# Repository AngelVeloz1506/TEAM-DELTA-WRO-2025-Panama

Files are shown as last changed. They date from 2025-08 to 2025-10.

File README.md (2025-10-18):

# TEAM DELTA — WRO 2025 (Future Engineers · Panama)

<p align="center" style="background-color:#1c1c1c; padding:20px; border-radius:12px;">
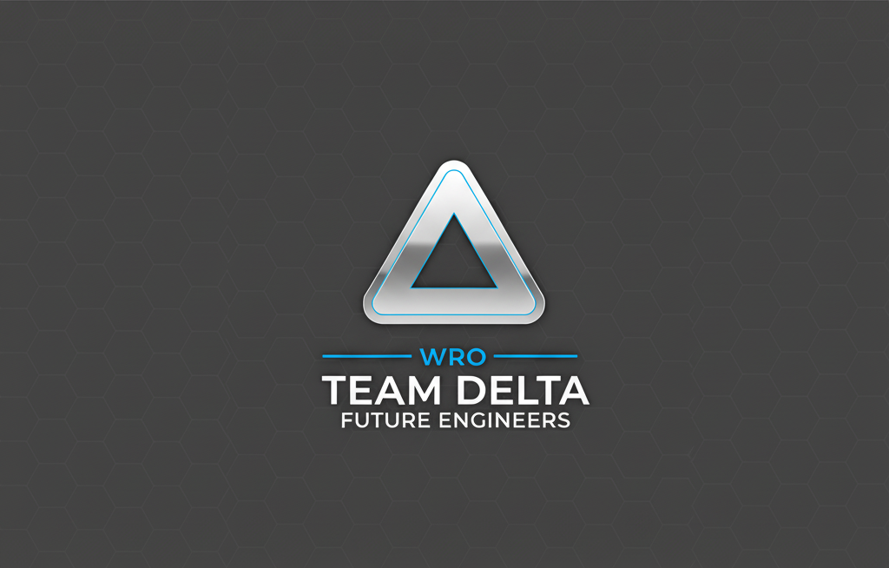
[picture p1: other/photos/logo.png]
Team Delta Logo
  
</p>

**Pontificia Universidad Católica Madre y Maestra (PUCMM) — Dominican Republic**  
Autonomous Vehicle Project for the **World Robot Olympiad 2025**, Future Engineers Category.

This repository documents the complete development of our robot — covering its **design, hardware, programming, and testing**.  



---

## Sections

<h2><a href="other/team/README.md">About Us</a></h2>

Team members, coach, and individual responsibilities.  
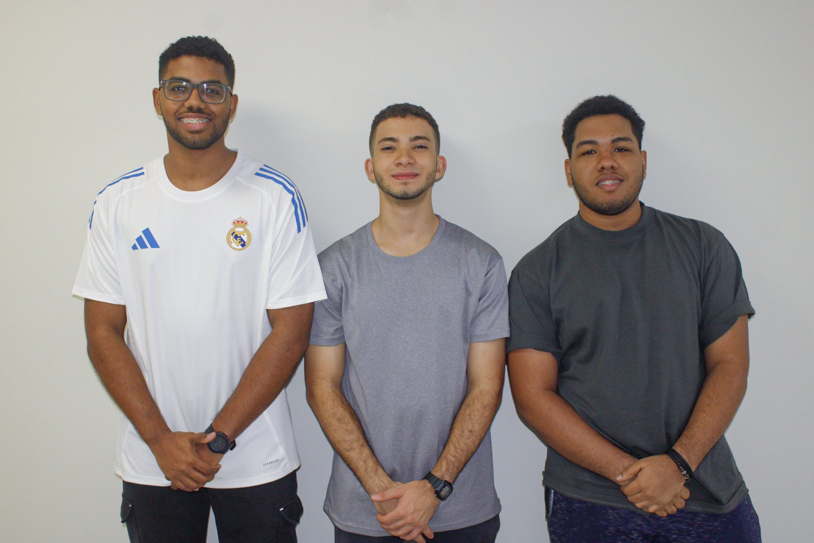
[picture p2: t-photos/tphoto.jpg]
About Us


<h2><a href="schemes/README.md">Hardware</a></h2>

Electronic components, wiring, power systems, and schematics.  
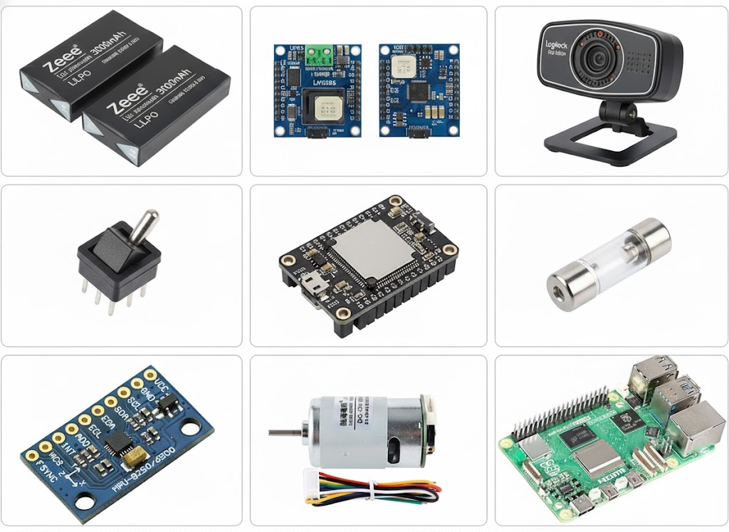
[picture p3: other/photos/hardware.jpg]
Hardware


<h2><a href="models/README.md">3D Design</a></h2>

Mechanical structure, chassis layout, and design evolution.  
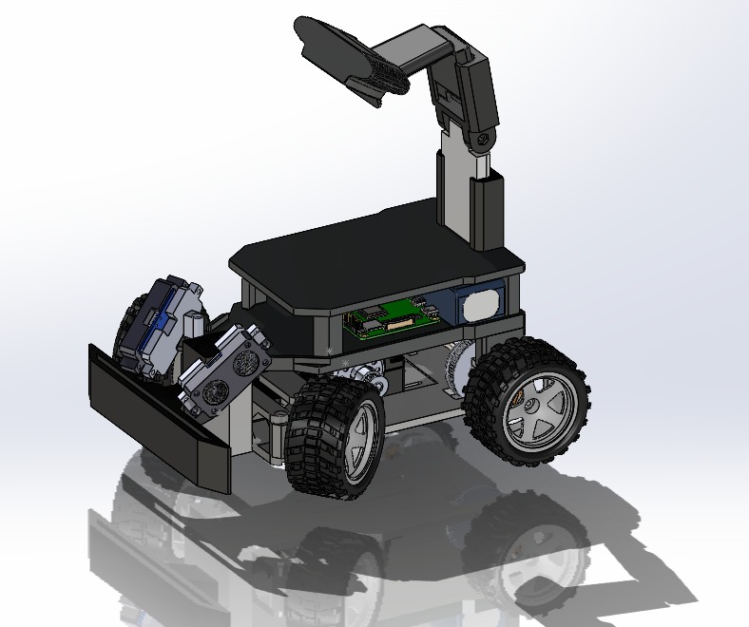
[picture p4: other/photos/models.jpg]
3D Design


<h2><a href="src/README.md">Software</a></h2>

Control logic, firmware explanation, and system architecture.  
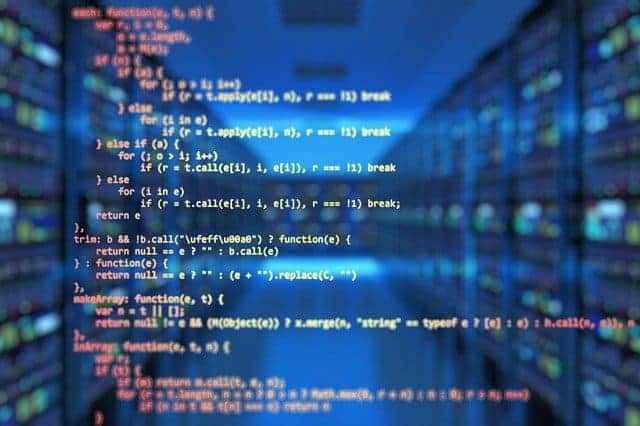
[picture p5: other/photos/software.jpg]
Software


<h2><a href="videos/README.md">Videos</a></h2>

Test runs, internal trials, and WRO challenges.  
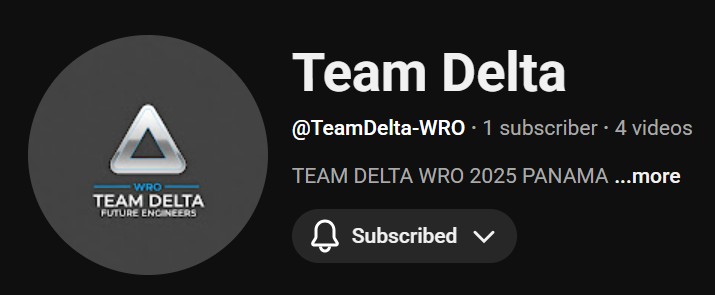
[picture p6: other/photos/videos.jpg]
Videos


<h2><a href="t-photos/README.md">Team Photos</a></h2>

Official and funny team pictures.  
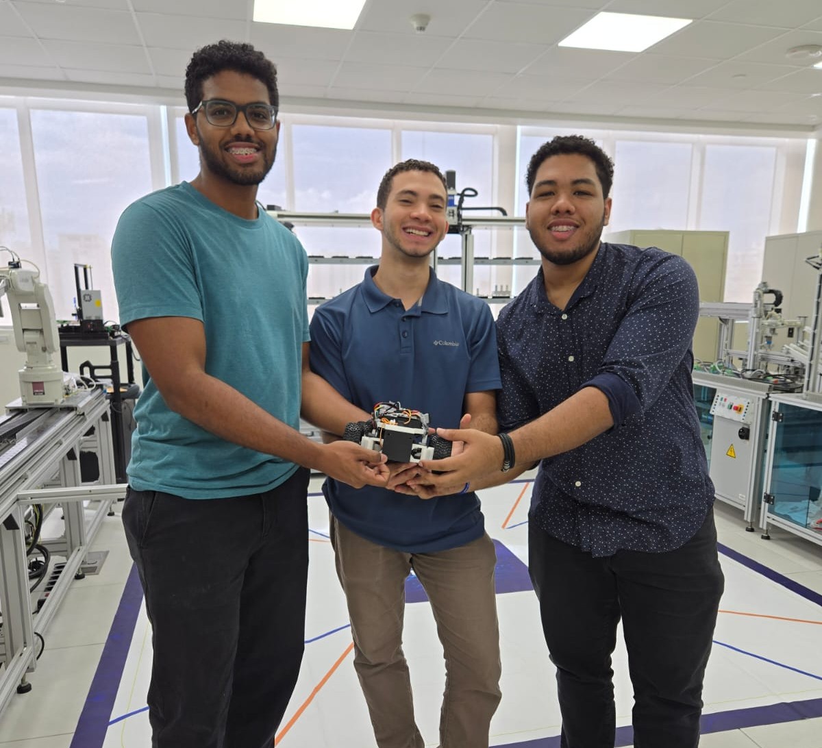
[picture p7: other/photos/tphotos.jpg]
Team Photos


<h2><a href="v-photos/README.md">Vehicle Photos</a></h2>

Design and evolution of the robot through different versions.  
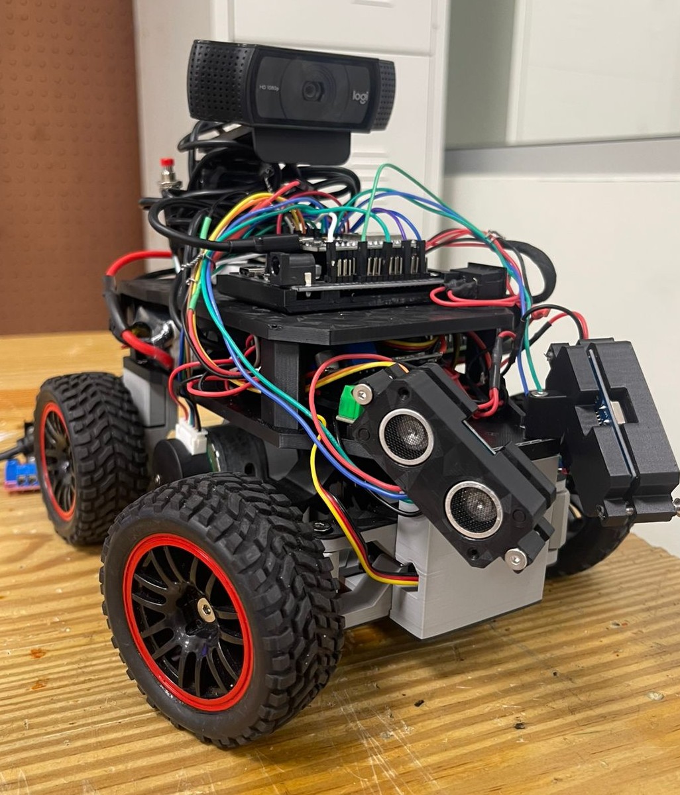
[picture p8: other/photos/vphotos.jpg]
Vehicle Photos


---

## Summary

**TEAM DELTA Δ** is committed to engineering excellence, innovation, and teamwork.  
This documentation serves as a transparent record of our journey to the **WRO 2025** stage,  
where mechanical design, electrical systems, and embedded control come together to build an autonomous vehicle capable of intelligent navigation.

---

*© 2025 TEAM DELTA – PUCMM · All rights reserved.*

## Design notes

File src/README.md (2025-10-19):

   This module implements the control logic for an autonomous robot car using:
   - **ESP32** as the main microcontroller  
   - **Servo motor** for Ackermann steering  
   - **1 DC motor** driven by a **DRV8871 H-Bridge** (PWM + brake)  
   - **2 ultrasonic sensors (HC-SR04)** for left/right distance measurement  
   - **MPU6050 IMU** for yaw estimation (gyro integration)  
   - **Incremental encoder** (channel A + channel B for direction)  
   - **Start button** with blocking logic at startup  

   ---

   ## System Overview

   1. **Sensing**
      - **Ultrasonics**: measure left/right distances with a **median of 3** for robustness.  
      - **IMU (MPU6050)**: reads raw accelerometer/gyroscope and integrates **gz** to estimate **yaw angle** in degrees.  
      - **Encoder**: ISR on channel A, with channel B defining the rotation direction. Used to calculate **position pulses** and **RPM** every 300 ms.

   2. **Control Strategy**
      - **Steering**: computed from the **difference** between left/right distances (`diff = d1 - d2`) mapped to servo angles.  
      - **Speed**: mapped from **accelerometer X-axis** (accelX in m/s²) to PWM duty cycle (115–255).  

   3. **Actuation**
      - **Servo**: controlled with `Servo.write(angle)`.  
      - **Motor**: controlled via `ledcWrite(motorPin, duty)` at **10 kHz**; `otherPin` is used for active brake.  

   4. **State Management**
      - **Startup lock**: waits for button press before motor activation.  
      - **Stop condition**: if `pos >= 3200` pulses, motor stops permanently.  

   ---

   ## Hardware and Pin Mapping

   ### Encoder
   - `SA = 27` → Channel A (interrupt, RISING)  
   - `SB = 14` → Channel B (direction sense)  

   ### Start Button
   - `BUTTON_PIN = 23` (INPUT_PULLUP; pressed = LOW)  

   ### Ultrasonics
   - Right sensor → `trigPin1 = 25`, `echoPin1 = 26`  
   - Left sensor → `trigPin2 = 32`, `echoPin2 = 33`  
   > **Note:** readings use **median of 3** with timeout handling.  

   ### Servo
   - `servoPin = 15`  
   - Default center (to be calibrated): `SERVO_CENTER = 87`  

   ### Motor + DRV8871
   - **PWM (speed)**: `motorPin = 12` (LEDC @ 10 kHz, 8-bit)  
   - **Direction/Brake**: `otherPin = 13`  

   ### IMU (MPU6050, I2C)
   - Connected via ESP32 default SDA/SCL  
   - Initialized with `mpu.initialize();`  

   ---

   ## Key Variables and Constants

   - `PULSOS_POR_REV = 12` → pulses per revolution of encoder  
   - `ENCODER_INTERVAL = 300 ms` → window for RPM calculation  
   - `PRINT_INTERVAL = 200 ms` → interval for logging yaw (currently commented)  
   - `yaw` → integrated heading in degrees  
   - `pos` → encoder pulses (signed)  
   - `rpm` → calculated every 300 ms  
   - `YAW_THRESHOLD = 5°`, `DIST_TRIGGER = 100 cm` (declared, not used yet)  

   ---

   ## IMU (Yaw Calculation)

   1. Read raw values:  
      ```cpp
      mpu.getMotion6(&ax, &ay, &az, &gx, &gy, &gz);
      ```
   2. Convert `gz` to deg/s:  
      ```cpp
      yaw_rate = gz / 131.0;
      ```
   3. Integrate:  
      ```cpp
      yaw += yaw_rate * dt;  // dt in seconds
      ```
   > No drift correction (no complementary or Kalman filter). Long runs will accumulate error.  

   ---

   ## Encoder: Position and RPM

   - **ISR** (`readEncoder`) increments or decrements `pos` depending on channel B.  
   - RPM calculation every 300 ms:  
   ```cpp
   delta = pos - lastPos;
   rpm = (delta / PULSOS_POR_REV) * (60000.0 / ENCODER_INTERVAL);
   ```  

   ---

   ## Ultrasonic Readings

   - `medirUna(trig, echo)`:  
   - Sends 10 µs trigger pulse  
   - Reads echo with timeout (25 ms max)  
   - Converts duration to cm  
   - Returns 400 if invalid (timeout or <3 cm)  

   - `medirDistancia(trig, echo)`:  
   - Takes **3 readings** with delays  
   - Returns the **median value**  

   ---

   ## Steering Logic

   - Computes difference: `diff = d1 - d2`  
   - Maps difference to servo angle:  
   ```cpp
   servoAngle = map(diff, -10, 10, 70, 110);
   servoAngle = constrain(servoAngle, 50, 120);
   serv.write(servoAngle);
   ```

   ---

   ## Motor Control (DRV8871)

   - Configured at **10 kHz, 8-bit resolution**  
   - Speed control via:  
   ```cpp
   ledcWrite(motorPin, duty);
   digitalWrite(otherPin, LOW);
   ```
   - Brake:  
   ```cpp
   digitalWrite(otherPin, HIGH);
   ledcWrite(motorPin, 255);
   delay(100);
   ledcWrite(motorPin, 0);
   ```

   ---

   ## Program Lifecycle

   ### `setup()`
   1. Initialize Serial, encoder pins, attach ISR  
   2. Start I2C and IMU  
   3. Configure ultrasonic pins  
   4. Configure start button (INPUT_PULLUP)  
   5. Attach servo, move to neutral  
   6. Setup motor PWM (LEDC)  
   7. **Wait loop**: blocks until button pressed for 2 s  

   ### `loop()`
   1. Measure distances (left/right ultrasonic)  
   2. Update yaw from IMU integration  
   3. Update RPM from encoder (every 300 ms)  
   4. Update steering angle (from ultrasonic diff)  
   5. Compute motor velocity (from accelX) and apply PWM  
   6. Stop permanently if encoder pulses exceed 3200  

   ---

   ## Calibration

   - **Servo center**: adjust `SERVO_CENTER` or apply offset until robot drives straight.  
   - **Ultrasonic mapping**: adjust `map(diff, -10..10)` to match your robot’s scale.  
   - **Motor scaling**: ensure accel axis matches forward movement; rescale if needed.  
   - **Encoder PULSOS_POR_REV**: must match your encoder hardware.  

   ---

   ## Safety Notes

   - Startup is blocked until button press (prevents accidental motion).  
   - Servo is constrained to 50–120° to avoid hardware damage.  
   - Motor brake is available but not actively used in main loop.  
   - Ultrasonics use timeout + median filtering to reduce noise.  
   - IMU yaw has drift; not suitable for long-term navigation without fusion.  

   ---

   ## Function Reference

   - `medirUna(trig, echo)` → single ultrasonic read  
   - `medirDistancia(trig, echo)` → median of 3 ultrasonic reads  
   - `readEncoder()` → ISR to update encoder pulses  
   - `setMotorSpeed(speed)` → set motor duty cycle (basic)  
   - `brakeMotor()` → apply active brake  

---

   ## Suggested Improvements

   - Add **PID speed control** using encoder feedback  
   - Use **complementary filter** for yaw correction  
   - Implement **fail-safe stop** when ultrasonic < threshold  
   - Expand to **bi-directional motor control** (two PWM inputs)  
   - Add **LED or buzzer** for startup/stop feedback  

---

## Previous Versions

For earlier iterations of the robot’s control system — including motion-only logic, PID stabilization, Pixy2 vision integration, and IMU-based yaw reset — see the  
**[Releases documentation](Releases/README.md)** located in the `src/Releases` directory.

This section details the evolution of the system through multiple code versions (`open-v1.ino` to `open-v4.ino`), showing how control strategies and sensor integration improved toward the final design.

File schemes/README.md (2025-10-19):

# Hardware

This section covers the **electronics, components (BOM), power**, and **schematics**.

---

## Bill of Materials (BOM)

| **Component** | **Qty** | **Notes** |
|---|---|---|
| [Raspberry Pi 5 (16 GB)](https://www.amazon.com/-/es/SC1113-Raspberry-Pi-5-16GB/dp/B0DSPYPKRG/ref=sr_1_1?sr=8-1) | 1 | Companion computer for vision & AI tasks |
| [ESP32](https://www.amazon.com/-/es/ESP-WROOM-32-Desarrollo-Microcontrolador-Procesador-Compatible/dp/B08D5ZD528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) | 1 | Main MCU, 3.3 V logic |
| [Logitech C920 Webcam](https://www.amazon.com/-/es/Logitech-correcci%C3%B3n-funciona-Facetime-port%C3%A1til/dp/B085TFF7M1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) | 1 | 1080p video input for vision processing |
| [HC-SR04 Ultrasonic Sensor](https://www.amazon.com/-/es/ultras%C3%B3nico-HC-SR04-distancia-Mega2560-Conjunto/dp/B01COSN7O6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) | 3 | Front, Left, Right (Echo shifted to 3.3 V) |
| [DRV8871 H-Bridge driver](https://www.amazon.com/-/es/Teyleten-DRV8871-controlador-H-puente-m%C3%B3dulo/dp/B0DN66P9XW/ref=sr_1_3?sr=8-3) | 2 | One per DC motor |
| [HS-485HB Servo (steering)](https://www.amazon.com/-/es/HS-485HB-Est%C3%A1ndar-Anal%C3%B3gico-Karbonite-Aircraft/dp/B0F9YB8P4B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) | 1 | 5–6 V supply, high torque |
| [DC Motor 12 V (RS555 model)](https://www.ebay.com/itm/155702183252?_skw=motor+encoder+r555+12v) | 2 | RS555 brushed motor |
| [MPU6050 (I2C)](https://www.amazon.com/giroscopio-magn%C3%A9tico-aceleraci%C3%B3n-acelerador-magnet%C3%B3metro/dp/B01I1J0Z7Y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) | 1 | IMU (gyro + accel) |
| [LiPo Battery 11.4 V 3000 mAh](https://www.ebay.com/itm/395464923168?_skw=zeee+11.4v+lipo+3s+3000mah) | 1 | XT60 recommended |
| [LM2596 / HW-083 step-down regulator](https://www.amazon.com/convertidor-reguladores-ajustables-recomendado-alimentaci%C3%B3n/dp/B0FDB25T5L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) | 2+ | 12→6 V (servo) and 12→5/3.3 V (logic) |
| [Main switch](https://www.amazon.com/interruptor-basculante-encendido-precableado-autom%C3%B3vil/dp/B07S2QJKTX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)|

> **Tip:** Always maintain a **common GND** across battery, drivers, sensors, and MCU.

---

## Key Modules

### Raspberry Pi 5 (16 GB)

<p align="center">
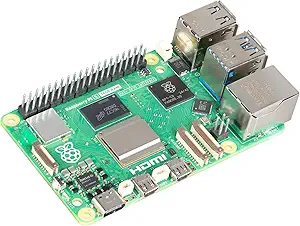
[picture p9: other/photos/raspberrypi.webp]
  <br>
  <em>The Raspberry Pi 5 serves as the companion computer for AI and computer vision tasks.<br>
  It communicates with the ESP32 via UART, I2C, or Ethernet for real-time data exchange.<br>
  Capable of running OpenCV, TensorFlow, and SLAM algorithms for perception and control.</em>
</p>

---

### ESP32 Controller

<p align="center">
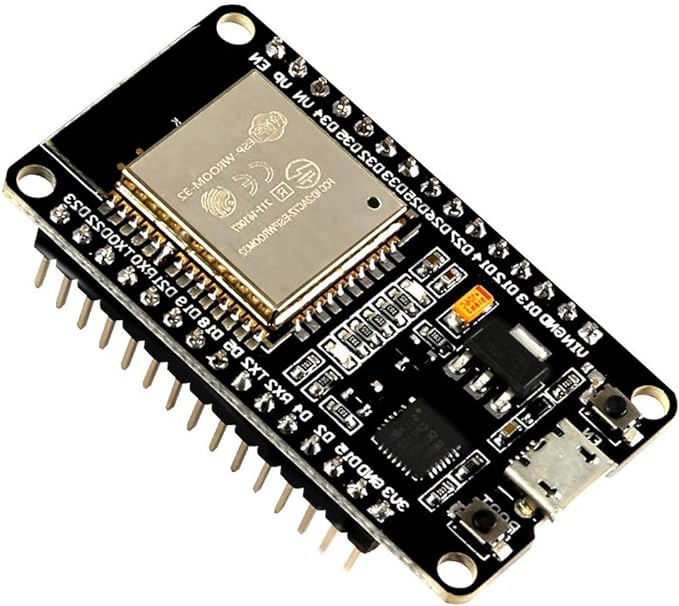
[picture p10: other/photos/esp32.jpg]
  <br>
  <em>The ESP32 functions as the main MCU, managing motor control, sensors, and communications.<br>
  Its dual-core architecture enables reliable real-time performance and parallel task execution.</em>

| Feature | Value |
|--|--|
| Cores | Xtensa LX6 dual-core |
| Voltage | 3.3 V |
| I/O Pins | 30+ |
| PWM (LEDC) | Yes |
| Flash | 4 MB |

</p>
---

### Camera (Logitech C920)

<p align="center">
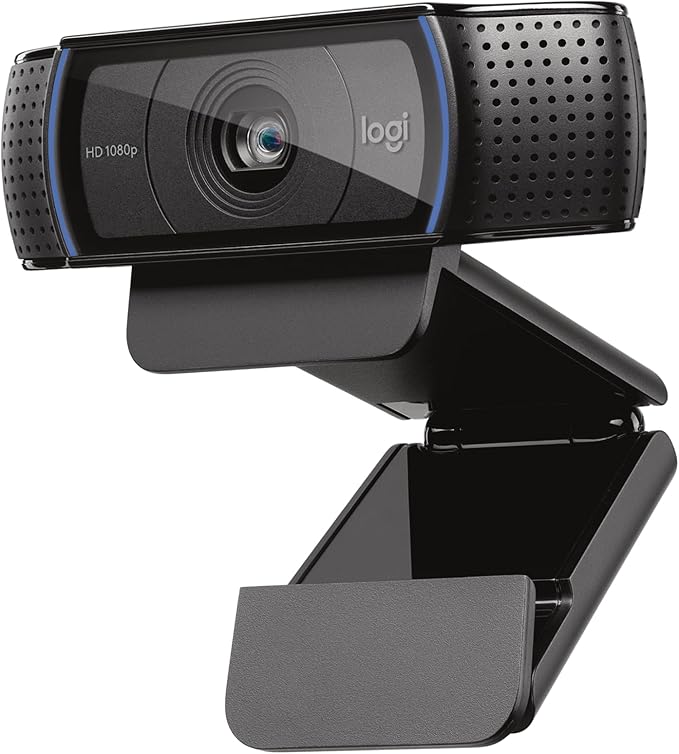
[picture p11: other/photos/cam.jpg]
  <br>
  <em>A 1080p USB camera used by the Raspberry Pi for lane and object detection.<br>
  Provides clear video input under different lighting conditions for AI vision processing.</em>
</p>

---

### Ultrasonic Sensor (HC-SR04)

<p align="center">
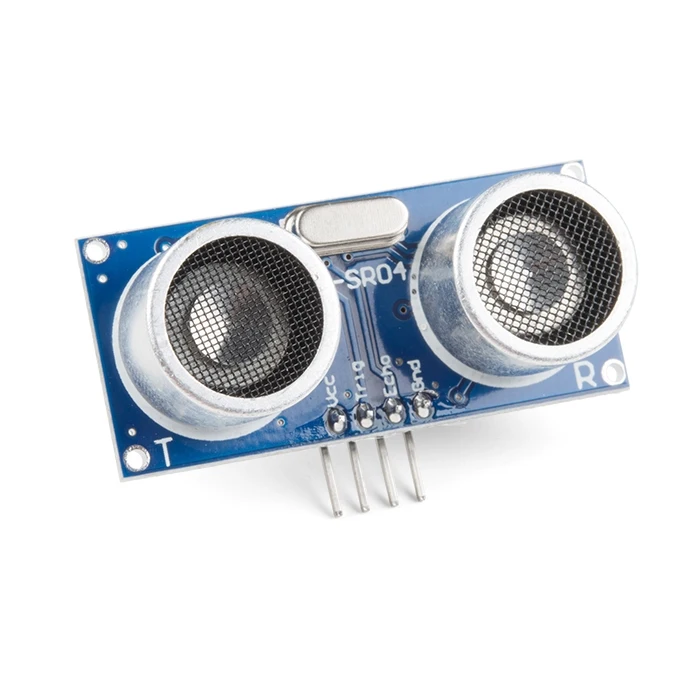
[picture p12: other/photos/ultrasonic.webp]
  <br>
  <em>Two ultrasonic modules are mounted front, left, and right to measure obstacle distance.<br>
  Each runs at 5 V (with 3.3 V logic shift) and 30 ms timeout for safe navigation.</em>
</p>

---

### H-Bridge (DRV8871)

<p align="center">
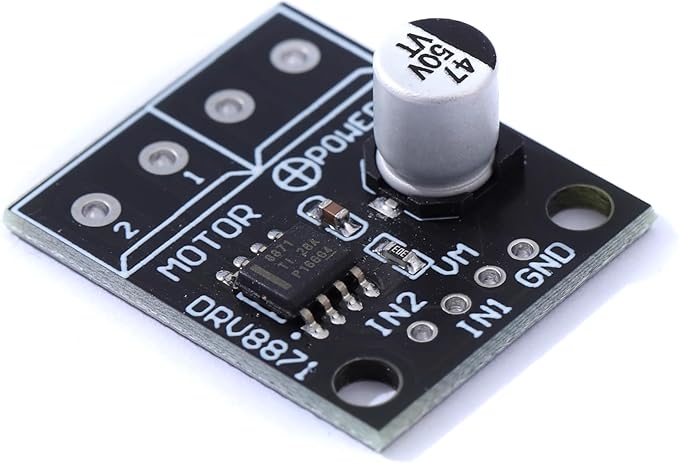
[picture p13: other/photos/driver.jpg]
  <br>
  <em>The DRV8871 controls each 12 V DC motor via PWM signals, allowing bidirectional rotation.<br>
  Supports current limiting and thermal protection for safe operation.</em>
</p>

---

### Servo (HS-485HB)

<p align="center">
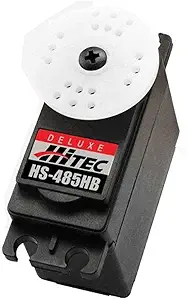
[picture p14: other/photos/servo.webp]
  <br>
  <em>The HS-485HB servo controls Ackermann steering using a dedicated 5–6 V supply (≥ 2 A).<br>
  Durable Karbonite gears ensure smooth and responsive direction control.</em>
</p>

---

### DC Motor (RS555 Model)

<p align="center">
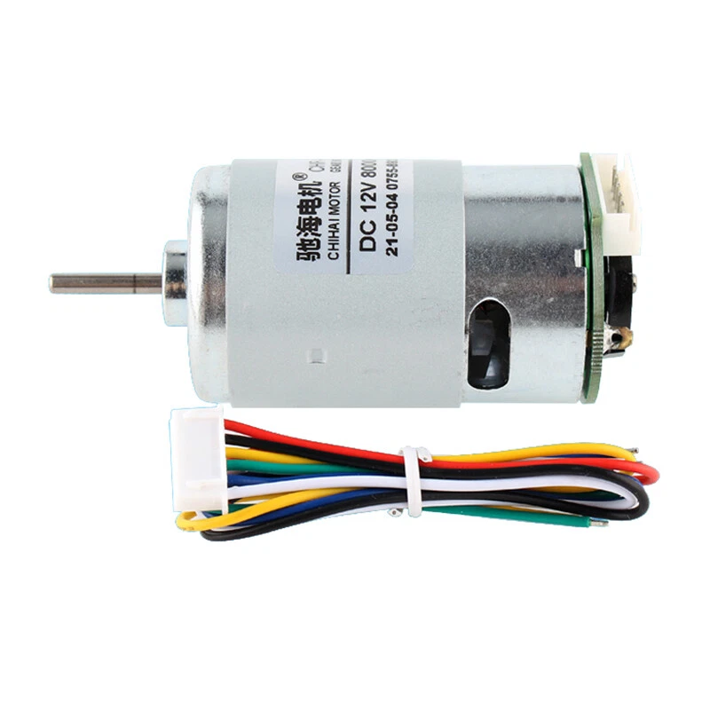
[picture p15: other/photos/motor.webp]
  <br>
  <em>A RS555 12 V brushed DC motor drive the rear wheels through an H-Bridges.<br>
  Provide high torque and stable speed under load conditions.</em>
</p>

---

### IMU (MPU6050)

<p align="center">
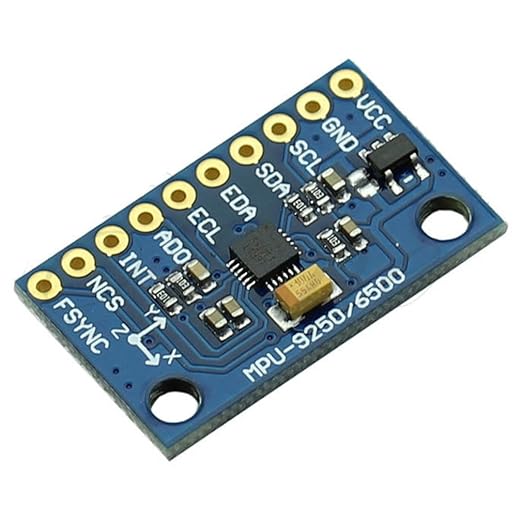
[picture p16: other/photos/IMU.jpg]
  <br>
  <em>The MPU6050 combines a 3-axis accelerometer and gyroscope to detect orientation and motion.<br>
  Sends I2C data to the ESP32 for stability and trajectory correction.</em>
</p>

---

### Battery (LiPo 11.4 V 3000 mAh)

<p align="center">
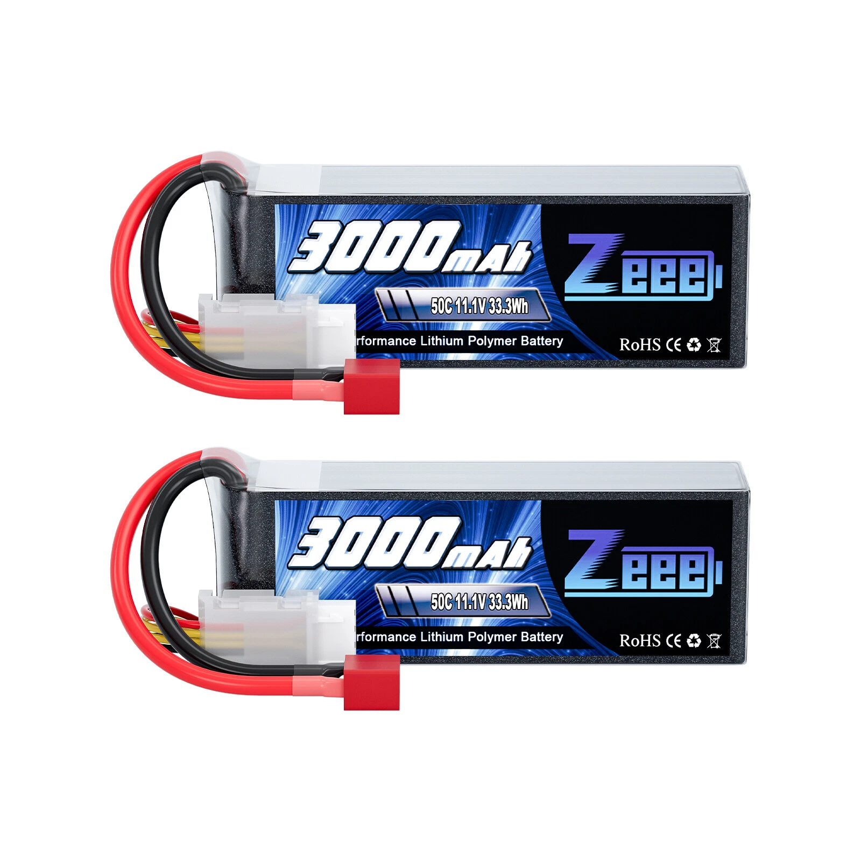
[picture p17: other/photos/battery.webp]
  <br>
  <em>A 3-cell LiPo battery powers all components with 11.4 V nominal voltage and XT60 connector.<br>
  Protected by inline fuses for safety and stable current delivery.</em>
</p>

---

### Step-Down Regulator (LM2596)

<p align="center">
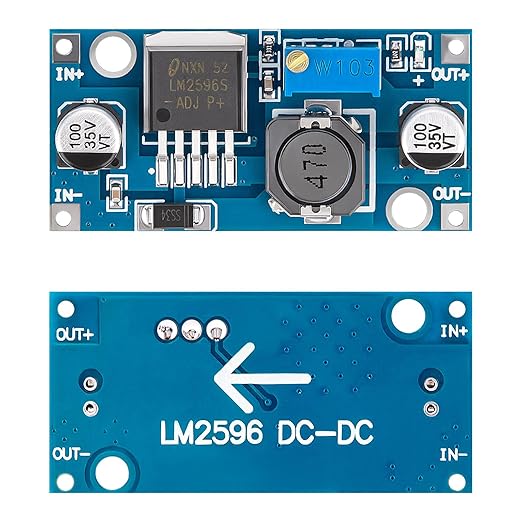
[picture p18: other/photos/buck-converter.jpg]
  <br>
  <em>LM2596 buck converters step 12 V down to 6 V (for servo) and 5/3.3 V (for logic).<br>
  Include adjustable outputs and thermal protection for reliable voltage regulation.</em>
</p>

---

### Main Switch

<p align="center">
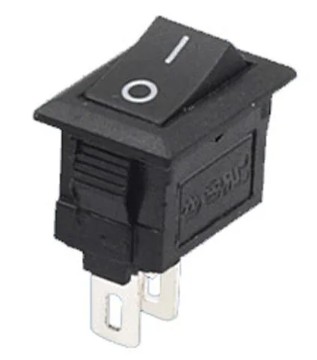
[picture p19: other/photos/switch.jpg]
  <br>
  <em>Main power switch ensures safe system startup.<br>
  Provides fast disconnect during maintenance or emergency shutdown.</em>
</p>

---

## Schematics

- [Delta Schematic Design (PDF)](../schemes/Delta%20schematic%20design.pdf)

**Preview**

<p align="center">
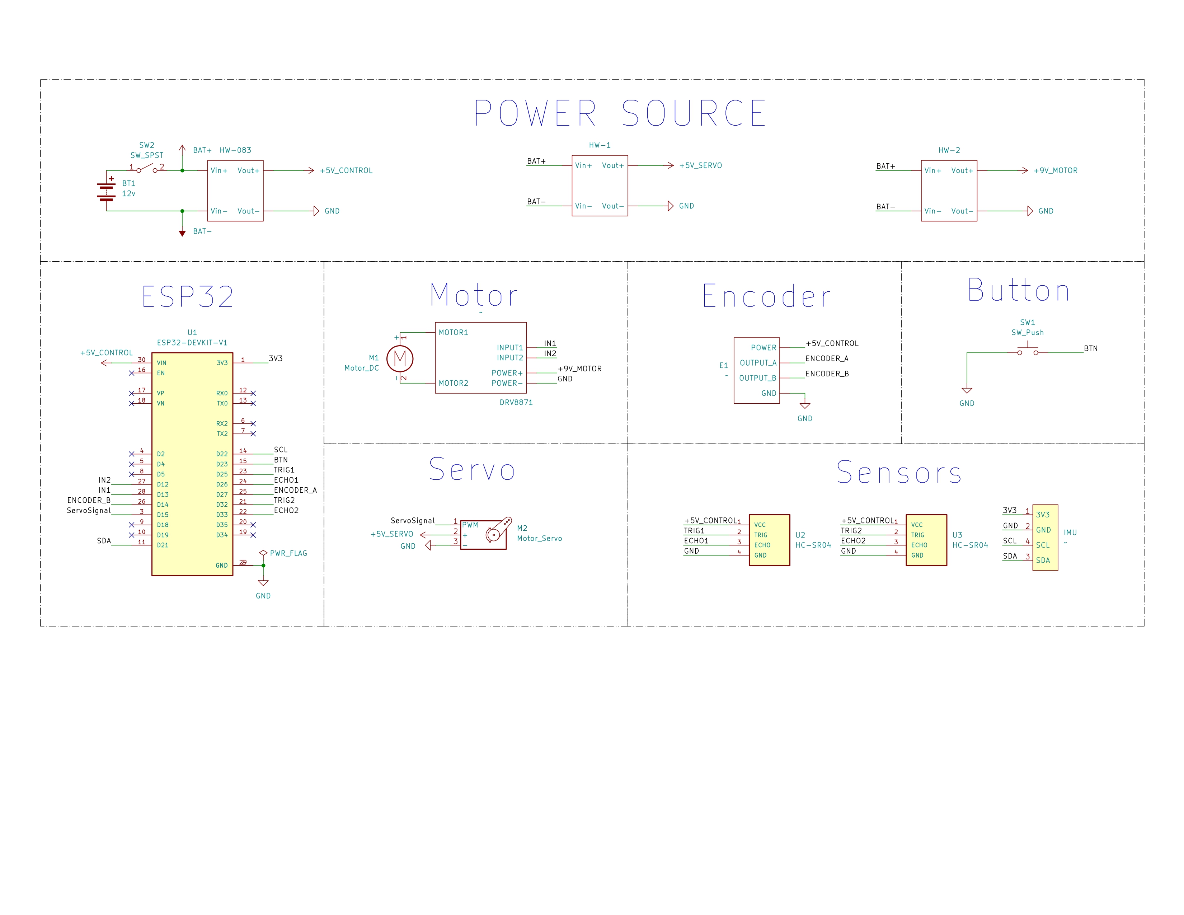
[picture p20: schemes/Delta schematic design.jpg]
  <br>
  <em>This diagram shows the ESP32, DRV8871 drivers, sensors, servo, regulators, and power distribution.</em>
</p>

---

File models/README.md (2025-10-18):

## Robot Design Evolution

This section showcases the **evolution of TEAM DELTA’s robot design**, from the very first mechanical prototype to the latest integrated version prepared for autonomous testing.  
Each stage demonstrates improvements in structure, balance, electronics integration, and overall system efficiency — reflecting the team’s continuous optimization process.

---

## Version 1 (V1)

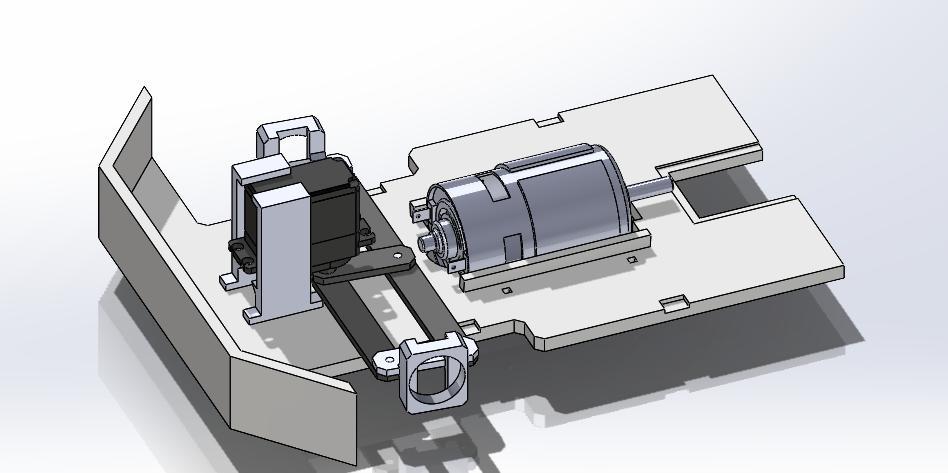
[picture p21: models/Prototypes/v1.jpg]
Version V1


The **first prototype** focused primarily on the **mechanical foundation and traction system** of the vehicle.  
At this stage, the design included a **simple frame** with a single DC motor mounted on a **metal support**, used to validate the basic drivetrain configuration.  
The purpose of V1 was to verify **axle alignment, transmission efficiency**, and **structural rigidity** under initial motion tests.  

No electronic modules or sensors were included yet — this prototype served as the **core mechanical proof of concept**.  
It helped the team understand torque distribution, friction losses, and the required power to achieve stable straight-line motion before integrating more advanced components.

---

## Version 2 (V4)

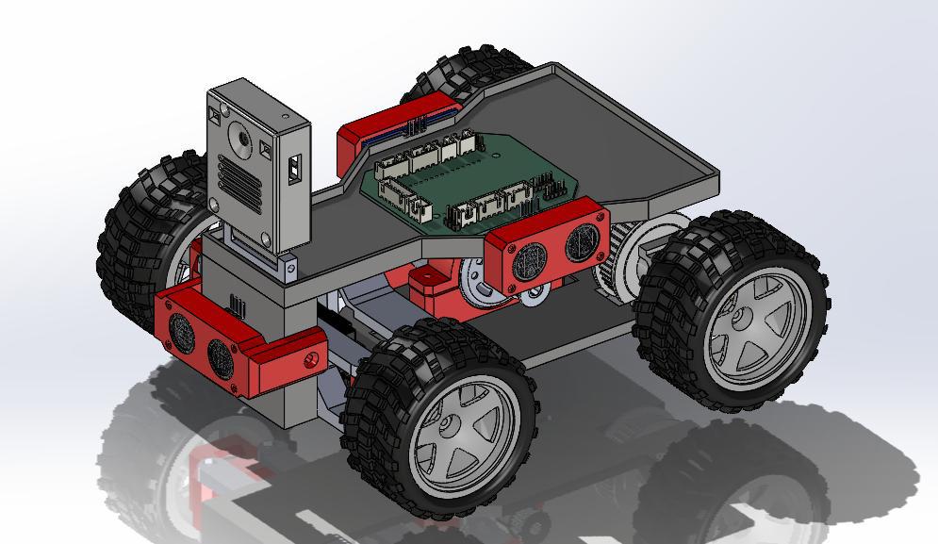
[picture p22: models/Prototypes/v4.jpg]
Version V4


The **second major iteration (V4)** introduced significant mechanical refinements and structural improvements.  
This version incorporated **four fully functional wheels**, connected through an upgraded **axle and gear system**, designed for improved torque balance and smoother motion.  

A **modular frame** was implemented, allowing rapid adjustments of the **motor position**, **axle supports**, and **servo linkages**.  
Weight distribution and the **center of gravity** were carefully optimized to enhance **stability**, particularly during turning and acceleration.  

The improved structural symmetry and reinforced chassis reduced vibrations and lateral drift, making V4 a **milestone version** in achieving consistent mechanical performance.

---

## Version 3 (V6.5)

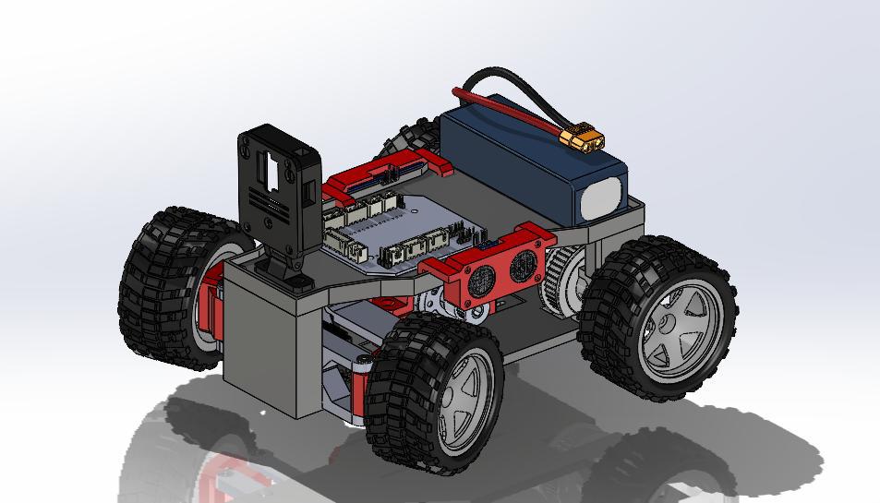
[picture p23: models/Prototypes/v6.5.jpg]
Version V6.5


The **third and most advanced version (V6.5)** represents the transition to a **fully integrated mechatronic platform**.  
This iteration introduced a dedicated **electronics control board**, organized **cable routing**, and **sensor mounts** for the front modules.  

The chassis was redesigned to be **more compact and layered**, providing specific areas for the **battery**, **controller**, and **camera or distance sensors**.  
This version combines mechanical robustness with clean electronic integration, marking the first time the system was ready for **autonomy, telemetry, and algorithm testing**.  

With improved accessibility, modular spacing, and a clear layout for expansion, V6.5 stands as the foundation for the team’s final **competition-ready design** — compact, efficient, and easy to maintain.

---

## Version 4 (V7)

Version V7

The **final version (V7)** showcases the **complete integration** of mechanical, electrical, and software subsystems, making it the team’s **competition-ready robot**.  
This design focuses on **system reliability**, **cable management**, and **sensor calibration** for autonomous operation under WRO conditions.  

The chassis now includes a **better mount for the camera** with a better and wider view of the field, beter **component positioning**, and **adjustable mounts** for ultrasonic units.  

Additionally, this version introduced **fans** to optimize cooling a new  power switch just for the Raspberry Pi so we can control both power sources independently.

V7 stands as the **culmination of iterative testing, engineering precision, and team collaboration**, ready to represent Team Delta at the **WRO 2025 Future Engineers** competition in Panama.

---

Each iteration — from V1 to V7 — represents a clear evolution in **engineering maturity**, moving from mechanical experimentation to an integrated, intelligent robotic system.  
The process highlights the importance of **incremental design, testing, and optimization** in achieving a stable and reliable autonomous platform.

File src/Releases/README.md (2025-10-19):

# Open Challenge — Code Evolution

This folder documents the **progressive versions** of Team Delta’s control code for the  
**WRO 2025 Future Engineers — Open Challenge**.  

Each version builds upon the previous one, introducing new sensors, control strategies, and optimizations for autonomous driving stability, accuracy, and response.

---

## **Version 1 — Basic Motion Control (Reverse-Kick and Power Boost)**

**File:** `open-v1.ino`  
**Main Components:** ESP32 + Servo (steering) + DRV8871 motor driver  

This first version establishes the **fundamental movement routine** for the robot — combining PWM motor control and steering using a servo.

### **Core Features**
- Modular helper functions for acceleration, braking, and turning.  
- Implements **reverse-kick braking** in every turn (short reverse pulses).  
- Adds a **power boost** after each braking event for smooth reacceleration.  
- Performs **three sequential right turns**, with duty cycle increase after the first turn.  
- On the **final turn**, the robot performs a full stop sequence:  
  - Reverse + brake + coast sequence for a complete halt.  

### **Code Breakdown**
- **Pin and PWM setup:**  
  Defines two motor pins (`IN_PWM`, `IN_OTHER`) controlling the DRV8871 H-bridge.  
  The PWM signal on `IN_PWM` drives forward speed, while `IN_OTHER` can toggle direction.  
  PWM is configured with `ledcAttach(channel, freq, res)` and commanded with `ledcWrite(channel, duty)`.
- **Motor control helpers:**  
  - `setForwardDuty(duty)` sets normal forward torque.  
  - `reverseKick(duty, ms)` momentarily switches PWM to the opposite pin to create a **short reverse pulse**, effectively braking the motor.  
  - `brakeHard()` energizes both inputs for strong electrical braking.  
  - `coast()` releases both pins for a free-spin stop.
- **Servo motion:**  
  The servo turns fully right for a corner (`turnRightMaxPower()`) and returns to center (`returnCenterMaxPower()`), both under controlled PWM drive.  
- **Duty logic:**  
  After the first turn, the work duty increases (`+30`) to compensate for frictional slowdown.  
- **Final Stop:**  
  The final loop executes `finalBrakeStop()` — a hard brake, reverse pulse, and final coast to stop completely.

---

## **Version 2 — MPU6050 Integration + PID Pitch Stabilization**

**File:** `open-v2.ino`  
**Main Components:** ESP32 + **MPU6050** Accelerometer + Servo + DRV8871  

This iteration introduced the **first sensor-based feedback control system** to measure inclination and stabilize the platform in real time.

### **Key Additions**
- **PID controller** (`PID_v1`) for pitch stabilization.  
- **Moving average filtering** to smooth sensor readings.  
- **Manual reset button** to re-zero sensor offsets.  
- **Boost phase** at startup for initial acceleration, then regulated power.  

### **Code Breakdown**
- **Sensor initialization & readout (I²C):**  
  Initializes the IMU over I²C, then reads raw acceleration on X/Y/Z every loop.  
  Data is converted to g’s and fed into a **moving-average filter** (ring buffer) for noise reduction.
- **Pitch calculation:**  
  Uses trigonometry to compute tilt:  
  `pitch = atan2(x, sqrt(y² + z²)) * 180/π` (degrees).  
  The filtered **pitch** becomes the **PID Input**.
- **PID control → steering:**  
  `Setpoint = 0` (level). `myPID.Compute()` calculates a correction sent to the servo with a safe clamp (e.g., 50–130°).  
  Proper tuning of **Kp/Ki/Kd** balances reaction speed and overshoot.
- **Motor drive policy:**  
  The motor runs at a defined **work duty** while the servo continuously adjusts heading based on the PID output to maintain stability.

---

## **Version 3 — Pixy2 Vision Integration**

**File:** `open-v3.ino`  
**Main Components:** ESP32 + Pixy2 Camera + Servo + DRV8871  

This version added **computer vision** capabilities for **color-based object detection** using the Pixy2 sensor.

### **Main Functionalities**
- Detects color blocks (signatures 1–2) via SPI communication.  
- Implements a **search behavior** through short forward pulses.  
- When a target is detected, performs a **turn and boost** maneuver.  
- Keeps the servo centered when idle.

### **Code Breakdown**
- **Camera initialization & reading:**  
  `pixy.init()` followed by `pixy.ccc.getBlocks()` each cycle reads detected objects.  
  Iterates `pixy.ccc.blocks[]` and checks `m_signature` for target classes (1 or 2).
- **Search gait (pulse & read):**  
  The robot advances in **short PWM bursts** (e.g., 20 ms on / 30 ms off) to reduce motion blur and give the camera stable frames.
- **Target reaction:**  
  On detection: pause → steer to a fixed angle → **boost** for `BOOST_TIME` → settle to a cruise duty.  
  This produces a decisive “detect → orient → accelerate” behavior.
- **Idle posture:**  
  With no detections, the servo **re-centers** (e.g., 90°) to maintain a straight scan line.

---

## **Version 4 — MPU6050 Gyro Integration + Yaw Reset Logic**

**File:** `open-v4.ino`  
**Main Components:** ESP32 + MPU6050 IMU + Servo + DRV8871  

This iteration integrates a **6-axis IMU (MPU6050)** combining gyroscope and accelerometer data to manage **orientation and heading** in real time.

### **Major Features**
- Real-time **yaw integration** from gyroscope data (`gz`).  
- Automatic **yaw reset** every ~1.5 s to mitigate drift.  
- **Autonomous stop** after six resets (lap completion logic).  
- **Active braking** with a brief **reverse** before final halt.  
- **Dynamic speed mapping** from longitudinal acceleration.

### **Code Breakdown**
- **IMU reading & integration:**  
  Reads `ax, ay, az, gx, gy, gz`.  
  Computes loop `dt` and integrates yaw: `yaw += (gz/131.0) * dt`.
- **Control mapping:**  
  - **Steering:** maps yaw to servo angle (e.g., 60–120°, clamped) to correct heading.  
  - **Speed:** maps longitudinal acceleration to PWM duty for forward thrust.
- **Yaw reset & stop logic:**  
  Every ~1.5 s: re-center yaw baseline and increment a **reset counter**.  
  After **six resets**: active brake → motor off → servo center → short reverse to clear the line → final idle.
- **Braking detail:**  
  DRV8871 **active brake** drives both inputs (brief pulse) to dissipate kinetic energy, enabling a crisp stop.

---
# Final Version — Open-Challenge.ino

This final version represents the **most complete autonomous control system** for Team Delta’s robot.  
It integrates all major hardware subsystems — motor, servo, sensors, and IMU — into a unified control architecture with **PID-based velocity regulation** and **sensor-fusion steering**.

---

## Control Architecture Overview

### 1) Motion Control (PID Feedback)
- Encoder readings (pins **SA=27**, **SB=14**) compute **wheel RPM**.  
- A **PID controller** adjusts the motor PWM output (`motorPin = 12`) to maintain a target RPM (`Setpoint = 1300`).  
- Gains (empirical):
  ```
  Kp = 0.54, Ki = 0.05, Kd = 0.0125
  ```
- Output clamped to **10–255** to avoid stalling/overdrive.

### 2) Steering via Ultrasonic Sensors
- Two HC-SR04 sensors (`trigPin1/echoPin1` right, `trigPin2/echoPin2` left).  
- Difference drives the steering servo:
  ```cpp
  int diff = d1 - d2;
  int servoAngle = map(diff, -15, 15, 47, 127);
  serv.write(constrain(servoAngle, 50, 130));
  ```
- Median-of-3 measurement for noise rejection.

### 3) IMU Yaw Integration
- **MPU6050** provides `gz` (deg/s); integrated with real `dt` to estimate **yaw**:
  ```cpp
  yaw += (gz / 131.0) * dt;
  ```
- Safety stop when yaw exceeds thresholds while path is straight (`diff < 5`):
  - Center servo.  
  - `ledcWrite(motorPin, 0);`  
  - Enter hold loop.

### 4) Startup & Safety
- Waits for **BUTTON_PIN = 17** (LOW) before arming.  
- DRV8871 direction pin (`otherPin = 13`) held LOW for forward; PWM on `motorPin`.

---

## Key Software Elements

- **Encoder velocity low-pass filter** (≈25 Hz):
  ```cpp
  v1Filt = 0.854 * v1Filt + 0.0728 * v1 + 0.0728 * v1Prev;
  ```
- **Ultrasonic read**: median of three with timeouts to avoid spikes.  
- **PID loop** runs continuously; PWM updated via `ledcWrite`.  
- **Permanent stop** conditions on excessive yaw.  
- **Button-gated startup** to prevent unintended motion.

---

## Related Work

For earlier development stages (motion-only, PID calibration tests, Pixy2 vision, IMU yaw reset), see the  
**[Releases documentation](../../Releases/README.md)** in `src/Releases/`.

---

Each code version represents a **milestone** in the robot’s autonomous development —  
progressing from **manual timing** to **sensor fusion and vision-based control**, building a strong foundation for the final **competition-ready system**.

---

*© 2025 TEAM DELTA — PUCMM · All rights reserved.*

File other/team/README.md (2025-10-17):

# About Us — Team Delta Δ

## Team Members — Pontificia Universidad Madre y Maestra (PUCMM)

<div align="center">

<table>
  <tr>
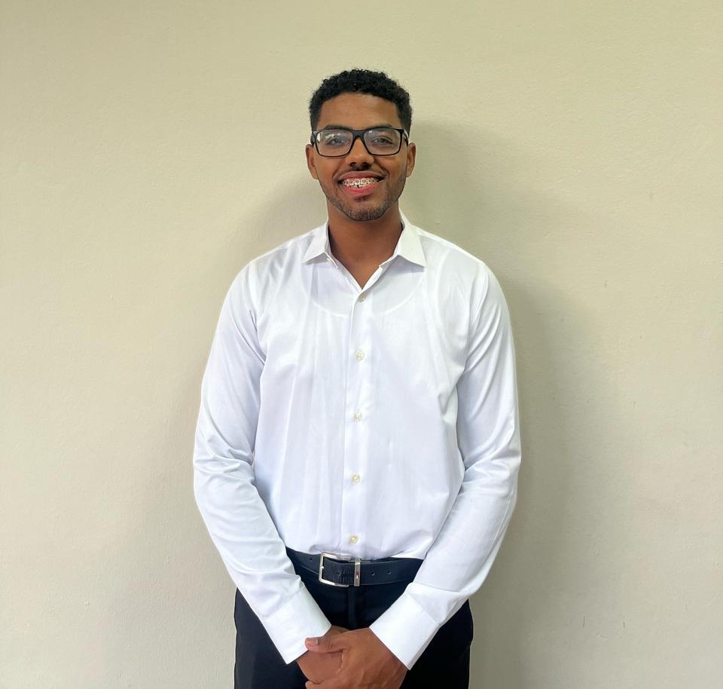
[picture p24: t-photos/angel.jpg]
Ángel Veloz
    <td></td>
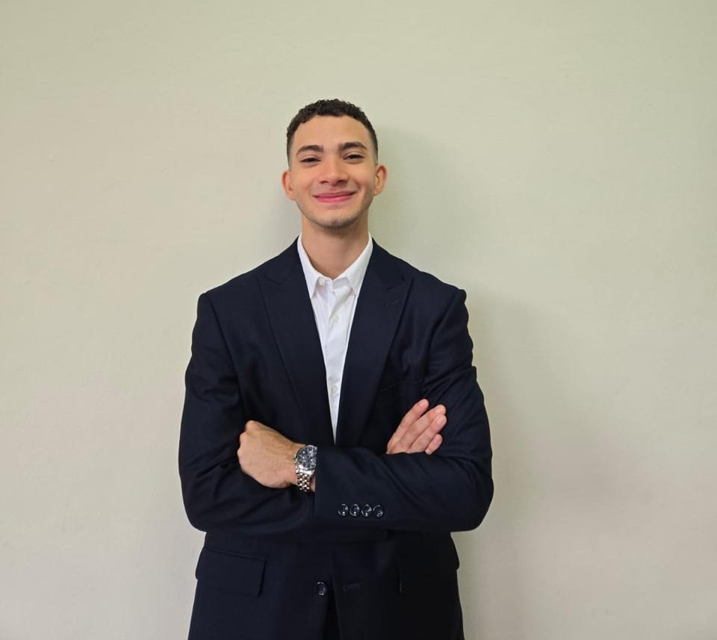
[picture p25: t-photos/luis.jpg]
Luis Lockward
    <td></td>
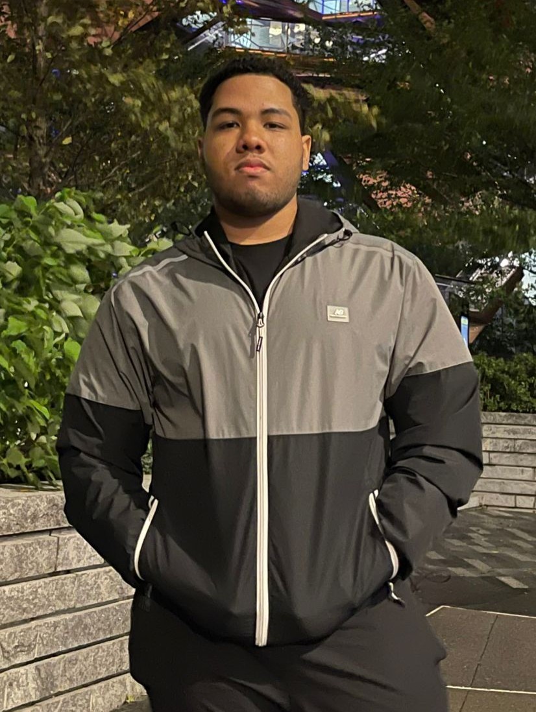
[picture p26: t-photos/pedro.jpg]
Pedro Pérez
    <td></td>
  </tr>
  <tr>
    <td><b>Ángel Veloz</b></td>
    <td><b>Luis Lockward</b></td>
    <td><b>Pedro Pérez</b></td>
  </tr>
</table>

<br>

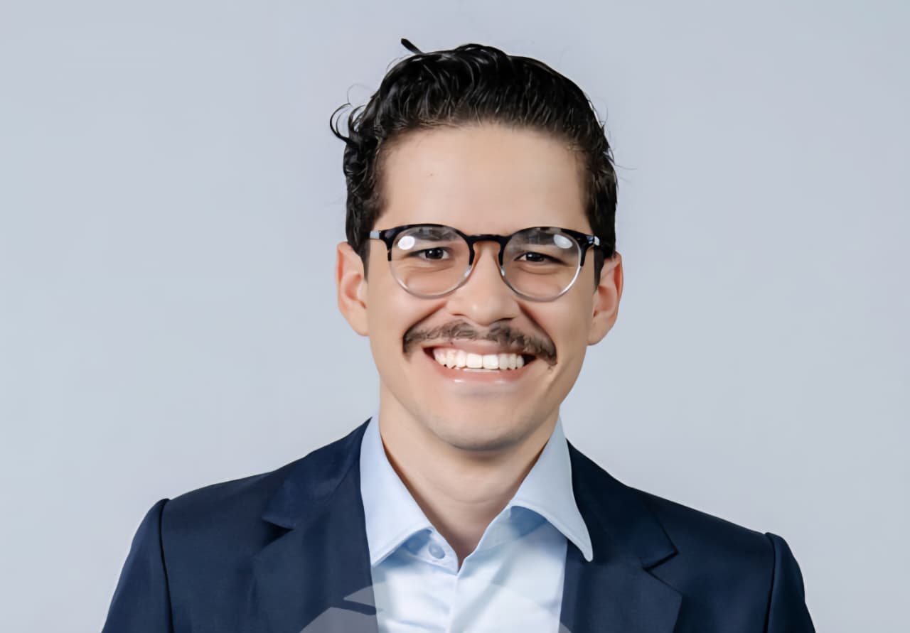
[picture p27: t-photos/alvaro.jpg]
Álvaro Zapata
<br>
<b>Álvaro Zapata — Coach</b>

</div>

---

> Emails  
> - Ángel Veloz — angelvelozsan1506@gmail.com  
> - Luis Lockward — luislockward@gmail.com  
> - Pedro Pérez — pedrojosepw@gmail.com  
> - Coach — alvarozapatazr@gmail.com  

---

## Roles & Responsibilities

### Ángel Veloz — Electrical Assembly & Circuit Design

Responsible for **electrical system design and integration**. Developed **PCB layouts**, power distribution, and wiring with **ESP32-WROVER**, **ToF/ultrasonic sensors**, and **MPU6050**. Ensures stable communications, power integrity, and sensor coordination.

---

### Luis Lockward — Mechanical Design & CAD Assembly

Leads **mechanical structure design and assembly** using CAD. Focus on a **lightweight, modular chassis** optimized for stability, maintenance, and compliance with WRO constraints. Oversees manufacturing and fit checks.

---

### Pedro Pérez — Programming & Control Systems

In charge of **software development and control logic** on the ESP32 (C++). Integrates sensors, motor control, and decision making. Optimizes **PID**, task scheduling, and module communications for autonomous behavior with Raspberry Pi (Python).

---

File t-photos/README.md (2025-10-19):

# Team Photos
---

## Official Photo

Official Photo

---

## Funny Photo

Funny Photo

---

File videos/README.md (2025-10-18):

# TEAM DELTA – Videos

## Official YouTube Channel

[**TEAM DELTA – YouTube Channel**](https://www.youtube.com/channel/UCRmfdBhCKCmFW21Ekp9HE9g)

This folder contains links to the project’s **video demonstrations and tests** for the  
**World Robot Olympiad 2025 – Future Engineers** category.

---

## TEST

- **First Successful Lap:** [https://www.youtube.com/shorts/PBy4HdEL0ig](https://www.youtube.com/shorts/PBy4HdEL0ig)  
- **First Try:** [https://www.youtube.com/shorts/hWiB3vBD0dU](https://www.youtube.com/shorts/hWiB3vBD0dU)  
- **First Time Laps without crash:** [https://youtu.be/oTMJWTLSgYg](https://youtu.be/oTMJWTLSgYg)

---

## Challenges

This section showcases the robot’s performance during the **WRO Challenges**, demonstrating real-time navigation, lane detection, and obstacle management under competition conditions.

- **Open Challenge:** [https://www.youtube.com/watch?v=eF5Osl_UWeE](https://www.youtube.com/watch?v=eF5Osl_UWeE)

---

## Fogueos

Every **Saturday**, Team Delta met to conduct **“fogueos”**, internal simulation sessions designed to replicate  
the **official competition environment** as closely as possible.  

During these sessions, the team performed full test runs following WRO challenge rules and timing.  
This practice allowed us to identify weaknesses in the robot’s design, control algorithms, and team coordination.  

Through each fogueo, we refined our **vehicle’s mechanical setup**, optimized **sensor calibration**,  
and improved **decision-making algorithms**, ensuring that by the time of competition,  
the robot performed with both **consistency and precision** under pressure.

- **Primer Fogueo:** [https://youtu.be/nUsMAf4XOtQ?si=Uxb-5inm45vHIkU7](https://youtu.be/nUsMAf4XOtQ?si=Uxb-5inm45vHIkU7)  
- **Segundo Fogueo:** [https://youtu.be/D-SDDrE8ES4?si=vfg2bzT9EzVwEiNM](https://youtu.be/D-SDDrE8ES4?si=vfg2bzT9EzVwEiNM)  
- **Último Fogueo:** [https://youtu.be/w9WrYO_HqlY](https://youtu.be/w9WrYO_HqlY)

---

*© 2025 TEAM DELTA – PUCMM · All rights reserved.*

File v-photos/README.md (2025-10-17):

# Robot Views — TEAM DELTA WRO 2025

This folder contains visual references of the robot from different perspectives.  
Each view is documented with its respective image.

---

## Front View

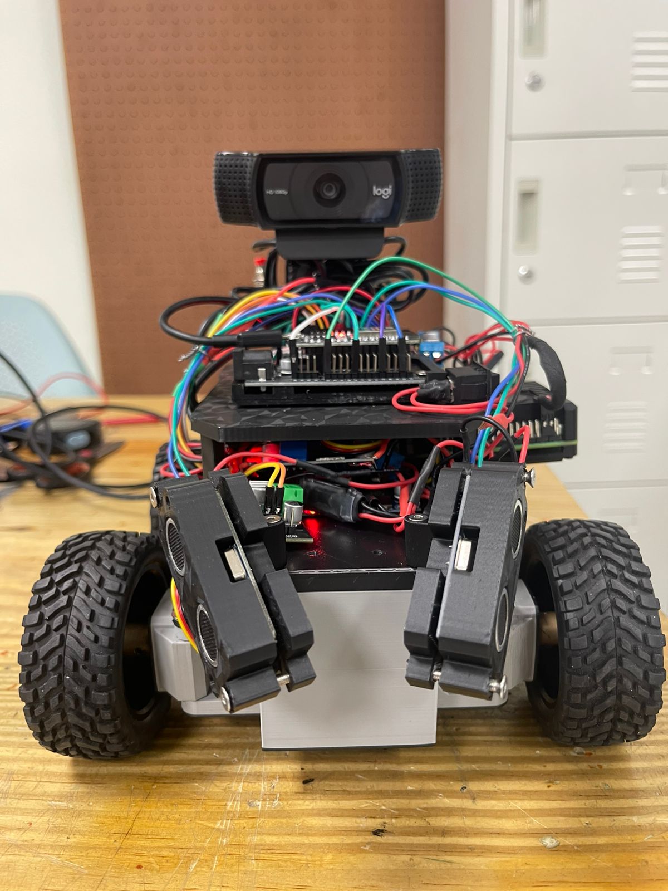
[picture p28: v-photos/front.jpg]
Front


---

## Back View

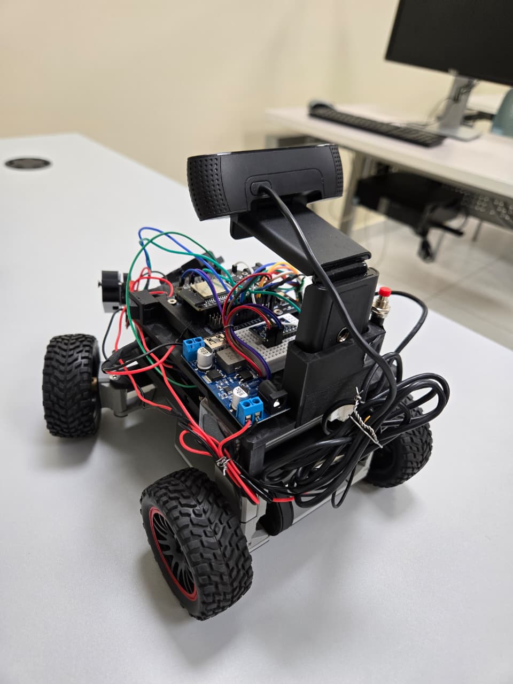
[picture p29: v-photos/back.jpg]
Back


---

## Left View

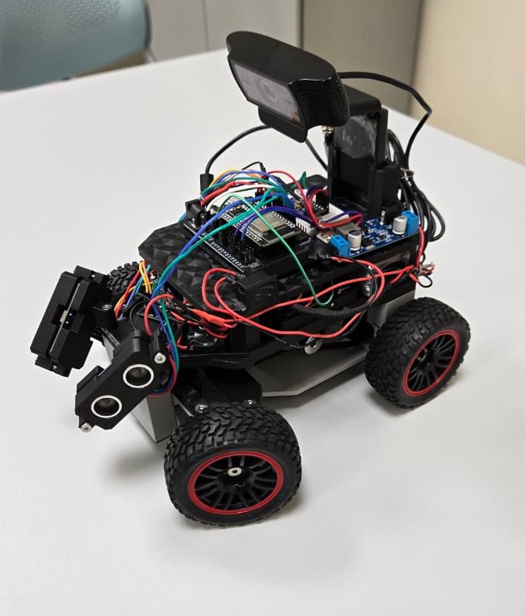
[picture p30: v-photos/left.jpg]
Left


---

## Right View

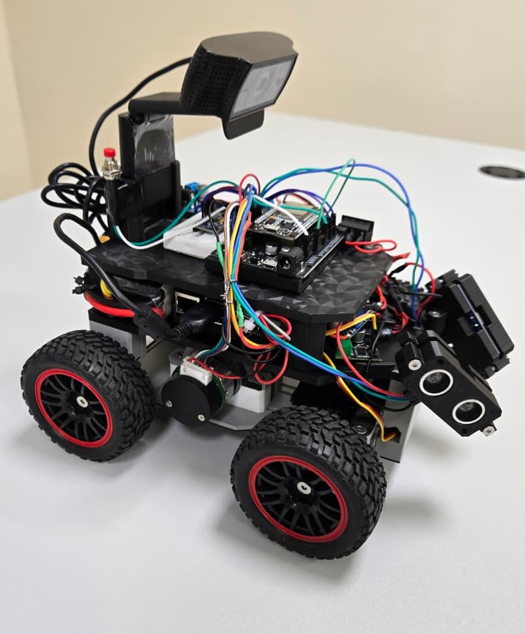
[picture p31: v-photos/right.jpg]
Right


---

## Top View

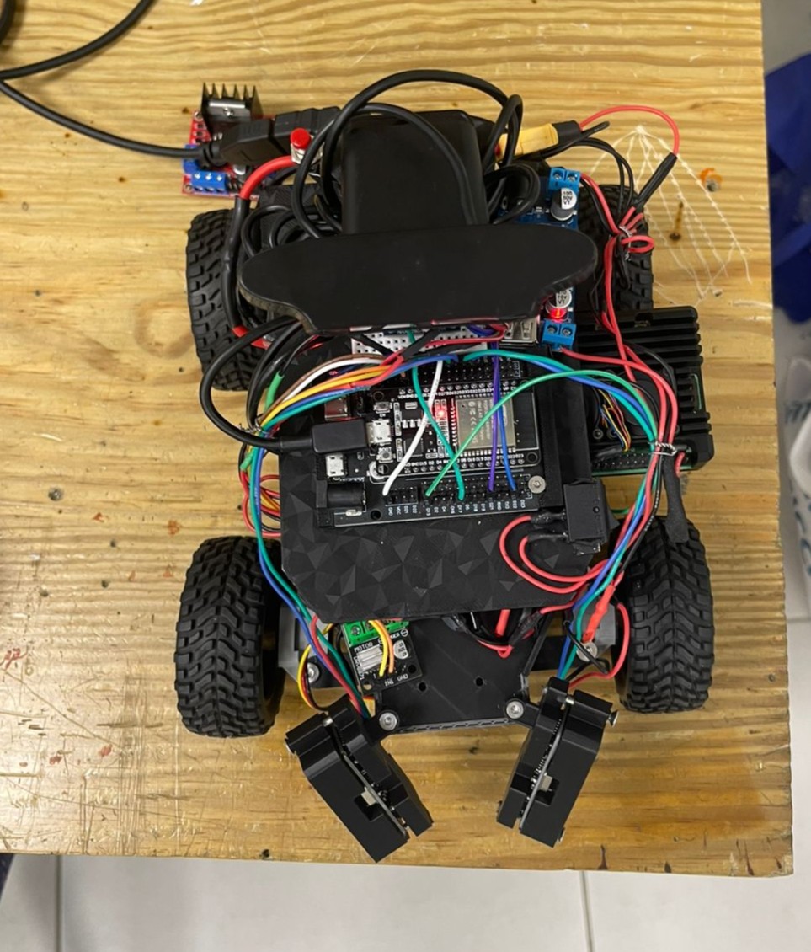
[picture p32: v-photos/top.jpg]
Top


---

## Bottom View

Bottom

---

## Isometric View

Isometric

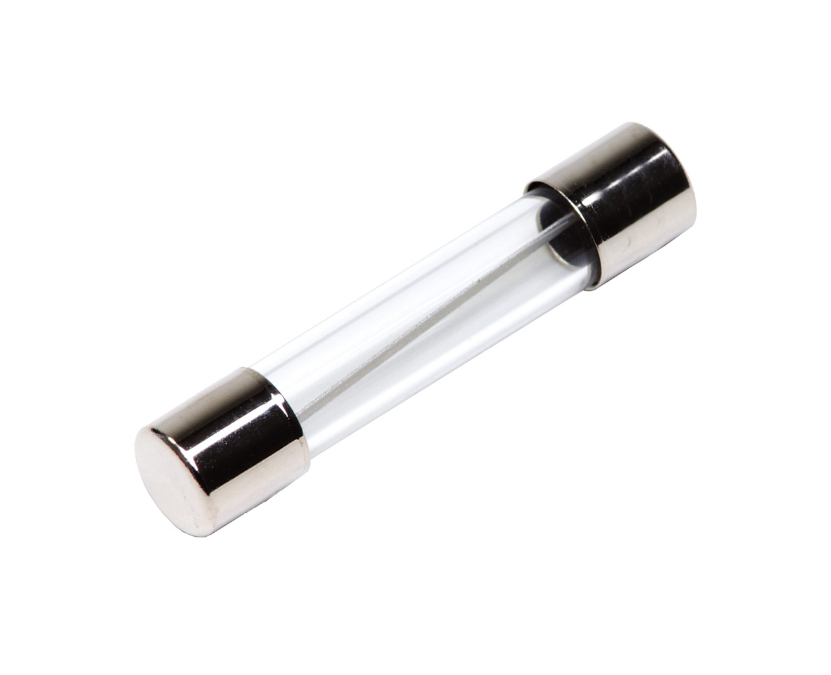
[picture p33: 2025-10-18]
other/photos/fuse.jpg

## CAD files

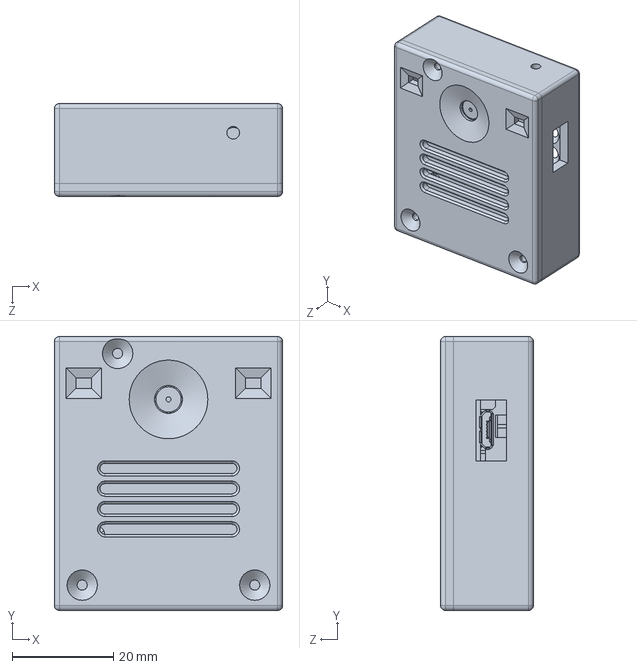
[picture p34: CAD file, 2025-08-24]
models/Prototypes/V6.5/Cam Full.SLDPRT
45.0 x 54.0 x 18.3 mm

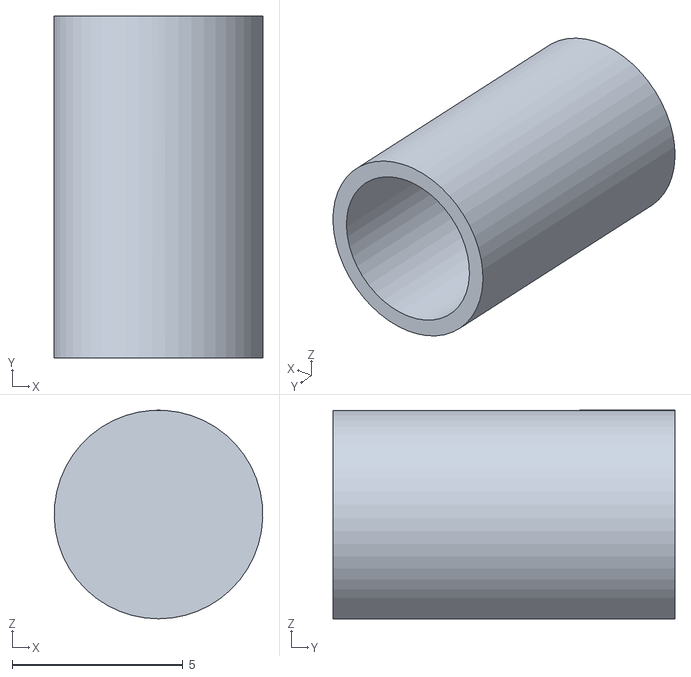
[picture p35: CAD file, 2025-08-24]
models/Prototypes/V6.5/STL/couplingimpresoalvaronobulto2.STL
6.10 x 10.0 x 6.10

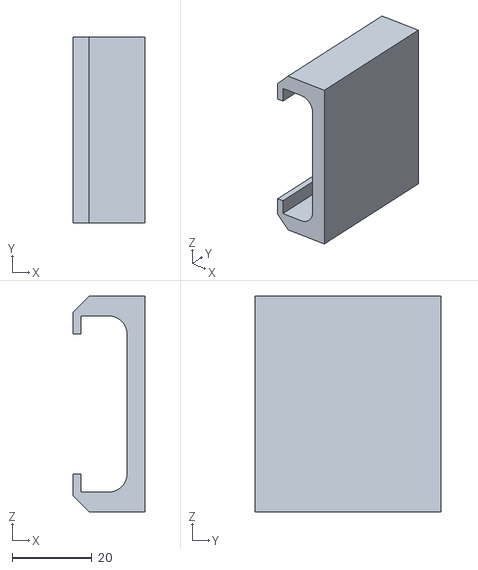
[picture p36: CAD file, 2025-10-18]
models/V7/Cam/Assem1 - CameraHolder-1.STL
18.0 x 46.4 x 54.0

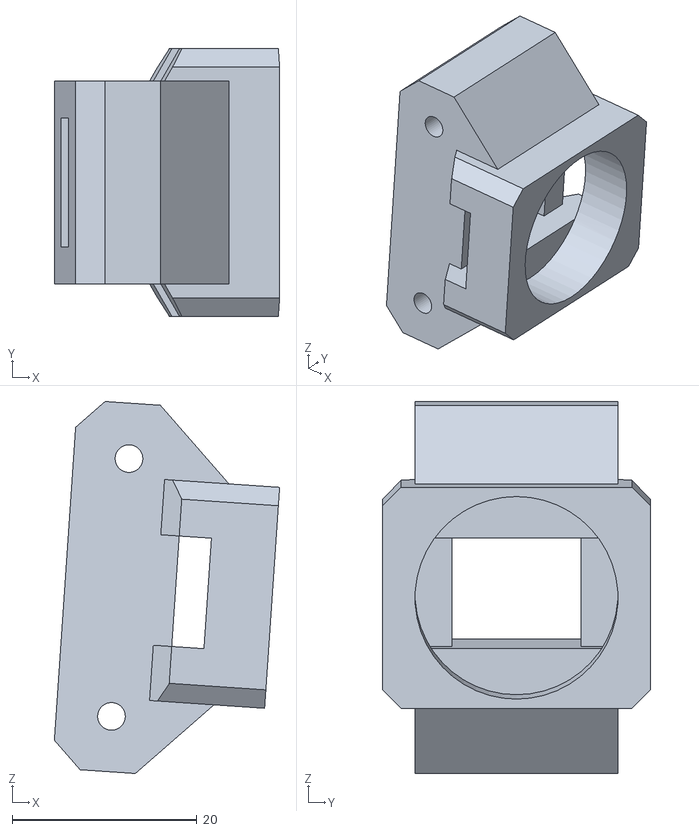
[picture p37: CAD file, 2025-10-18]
models/V7/STL/rrep/V6.5 - Giro 4-2.STL
24.4 x 29.0 x 40.3

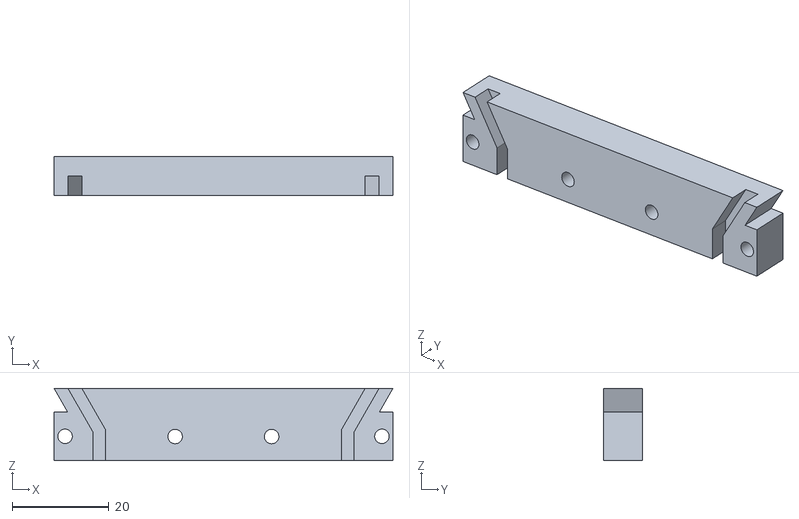
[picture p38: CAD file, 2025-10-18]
models/V7/STL/V6.5 - Sensore-1.STL
70.3 x 8.00 x 15.0

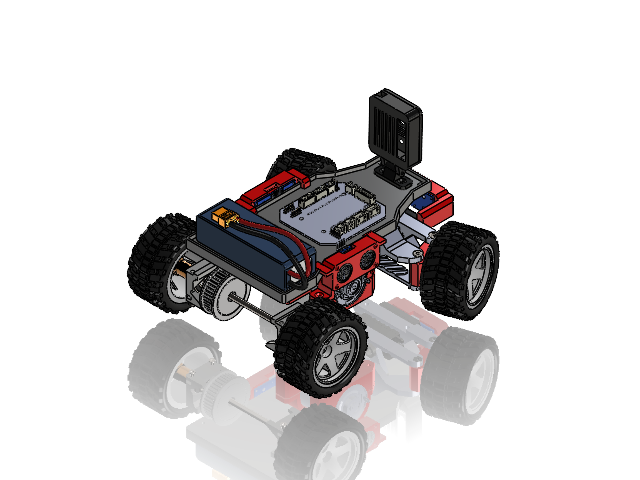
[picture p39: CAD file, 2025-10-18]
models/Prototypes/V6.5/V6.5.SLDASM
608RS x 4
Giro 2
Giro 2.1
Giro 2pr
Giro 4 x 2
Pasador
RowlockB x 2
Wheel2Bear x 2
DC Motor 555_12V
MotorHolder x 3
Shaft
MotorHolderL
Giro 2.1top
V3.1Wheel x 4
V3.1Tyre x 4
MotorHolder2B
Hex Coupling 6mm x 2
Shaft2HexCoupling x 2
Pulley1
Pulley2.step
ServoArm
mg995
Multistar_3000mAh_4S_Lipo_Battery
XT60 Buchse
Part3^Assembly_Multistar_Battery_3000mah
ultrasonic holder2 x 2
Ultrasonic sensor x 3
ultrasonic holderFront
WRO plugNplay
MotorHolder2.5B
Bearing2Shaft
m4 lock nut x 4
TopeServo
PixyCase1
PixyCase2
PixyCase3
socket countersunk head screw_am x 8

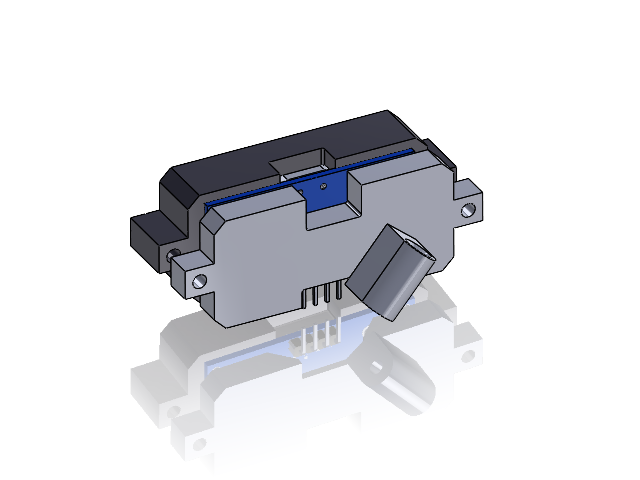
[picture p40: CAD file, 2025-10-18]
models/V7/Ultrasonico/Assem1.SLDASM
Ultr1 (1)
Ultr1 (2)
Part2L

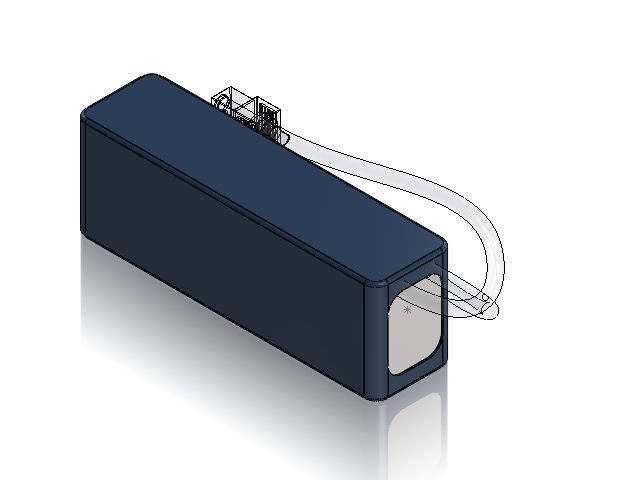
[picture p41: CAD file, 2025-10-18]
models/V7/Assembly_Multistar_Battery_3000mah.SLDASM
Multistar_3000mAh_4S_Lipo_Battery
XT60 Buchse
Part3^Assembly_Multistar_Battery_3000mah

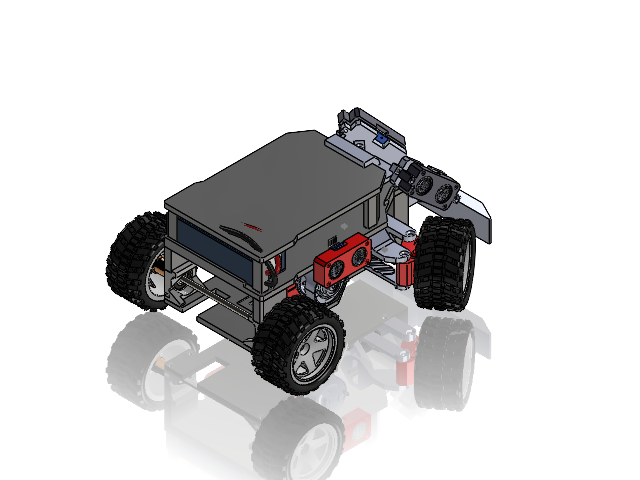
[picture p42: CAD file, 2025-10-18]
models/V7/V6.5.SLDASM
608RS x 4
Giro 2
Giro 2.1
Giro 2pr
Pasador
RowlockB x 2
Giro 4 x 2
Giro 2.1top
pulley11
Wheel2Bear x 2
DC Motor 555_12V
MotorHolder x 3
Shaft
MotorHolderL
V3.1Wheel x 4
V3.1Tyre x 4
MotorHolder2B
Hex Coupling 6mm x 2
Shaft2HexCoupling x 2
Pulley1
ServoArm
mg995
Multistar_3000mAh_4S_Lipo_Battery
XT60 Buchse
Part3^Assembly_Multistar_Battery_3000mah
ultrasonic holder2 x 2
Ultrasonic sensor x 2
MotorHolder2.5B
Bearing2Shaft
TopeServo
Ultr1 (2) x 2
Part2L
Ultr1 (1) x 2
fan holder
Bumper

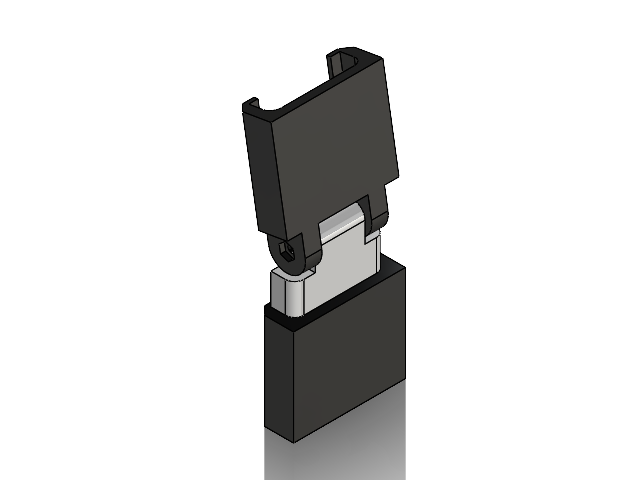
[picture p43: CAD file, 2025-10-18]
models/V7/Cam/Assem1.SLDASM
CameraHolder
CameraHolder2

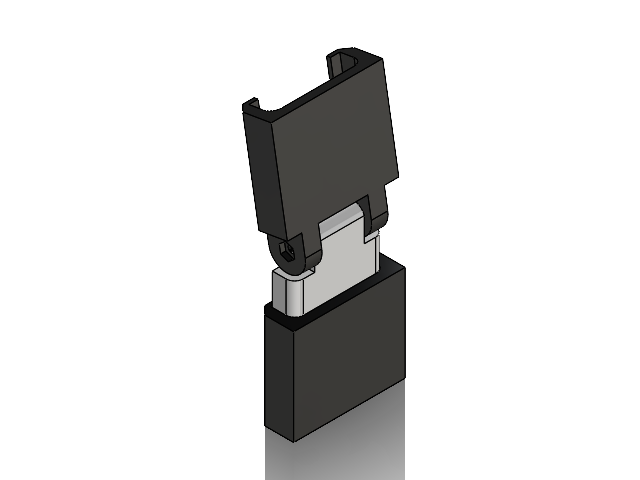
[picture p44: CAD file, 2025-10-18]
models/V7/Cam/CameraAsem.SLDASM
CameraHolder
Cam1
CameraHolder2

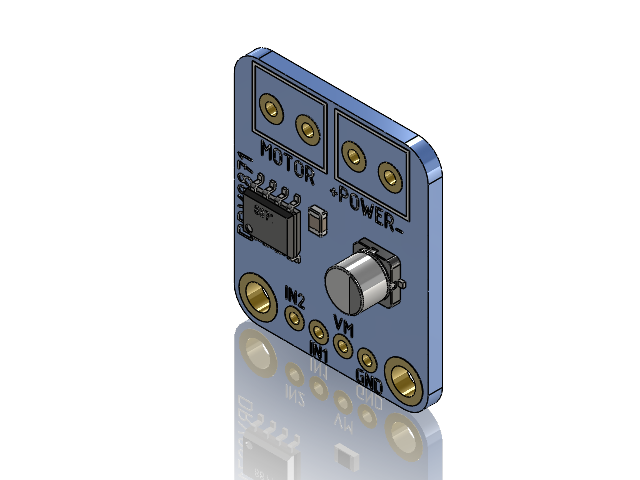
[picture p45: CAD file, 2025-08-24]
models/Prototypes/V6.5/DRV8871_module.SLDASM
SMD AEC (Base).stp
SMD AEC (Pin).stp x 2
SMD AEC (Cylinder).stp
DRV8871_module_PCB.stp
RESC-0805.stp
CAPC-0805-T0.stp
DRV8871_R-PDSO-G8.stp

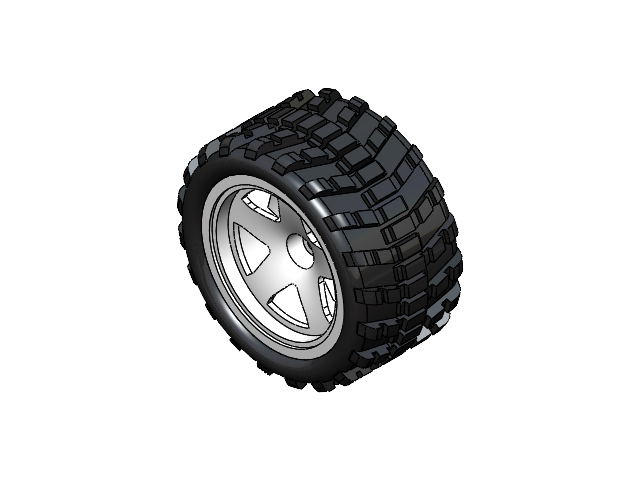
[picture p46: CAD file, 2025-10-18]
models/V7/Wheel.SLDASM
V3.1Wheel
V3.1Tyre

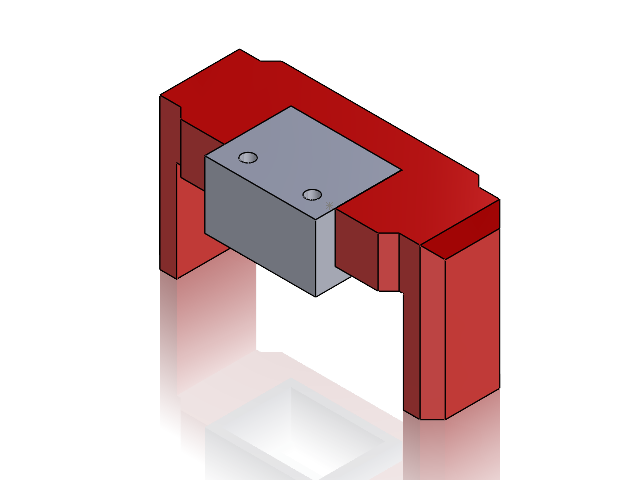
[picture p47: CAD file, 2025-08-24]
models/Prototypes/V6.5/IMUComp.SLDASM
imu holderFront
IMU case

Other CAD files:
models/Prototypes/V6.5/Wheel.SLDASM
models/Prototypes/V6.5/Assembly_Multistar_Battery_3000mah.SLDASM
models/V7/Ultrasonico/Part2.SLDPRT
models/Prototypes/V1/775 motor u.SLDPRT
models/Prototypes/V1/BaseMotor.SLDPRT
models/Prototypes/V1/CajaB2Shaft.SLDPRT
models/Prototypes/V1/CajaB2Shaft.STL
models/Prototypes/V1/ChumaseraTr.SLDPRT
models/Prototypes/V1/ChumaseraTr.STL
models/Prototypes/V1/ChumaseraTr2.SLDPRT
models/Prototypes/V1/ChumaseraTr2.STL
models/Prototypes/V1/Eje2Dif.SLDPRT
models/Prototypes/V1/Eje2Dif.STL
models/Prototypes/V1/Escalon.SLDPRT
models/Prototypes/V1/Escalon.STL
models/Prototypes/V1/Estructura.SLDPRT
models/Prototypes/V1/Estructura.STL
models/Prototypes/V1/EstructuraAS.SLDASM
models/Prototypes/V1/EstructuraSup.STL.SLDPRT
models/Prototypes/V1/Giro 1.SLDPRT
models/Prototypes/V1/Giro 1.STL
models/Prototypes/V1/Giro 2.SLDPRT
models/Prototypes/V1/Giro 2.STL
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

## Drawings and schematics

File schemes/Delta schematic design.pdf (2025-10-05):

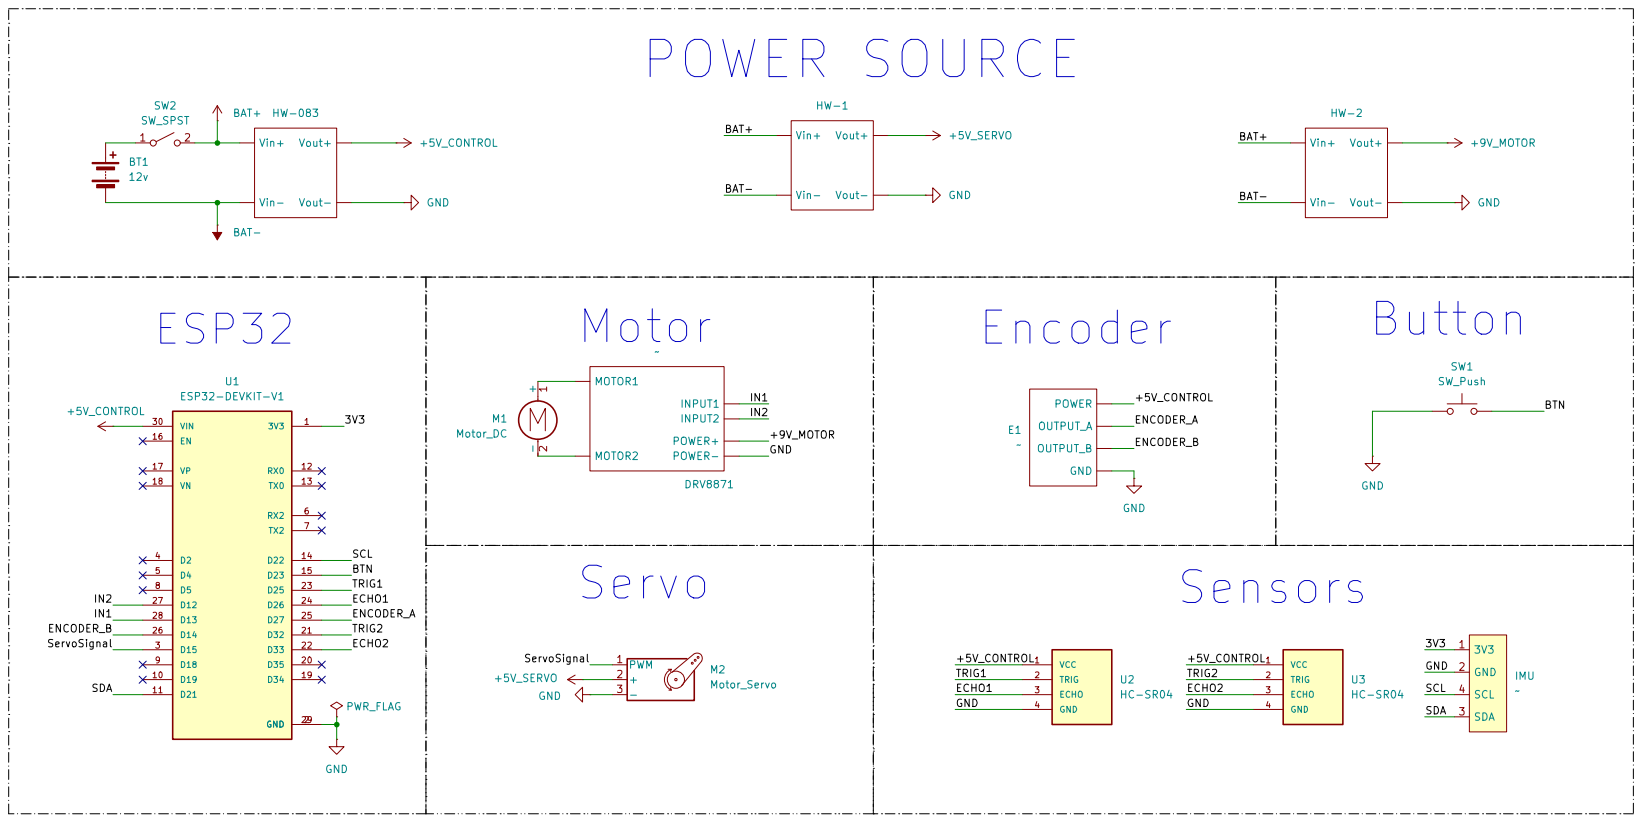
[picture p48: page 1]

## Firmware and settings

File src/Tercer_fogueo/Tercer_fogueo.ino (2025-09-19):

#include <Arduino.h>
#include <ESP32Servo.h>
#include "Wire.h"
#include "I2Cdev.h"
#include "MPU6050.h"

#define SA 27
#define SB 14

int pos = 0;   // posición absoluta (pulsos)
int lastPos = 0;
int rpm = 1;

// Ajusta según tu encoder
const int PULSOS_POR_REV = 12;
unsigned long lastTimeza = 0;   // encoder timer
const unsigned long ENCODER_INTERVAL = 300; // ms

// --- Global variables ---
float targetYaw = 0;
bool correctingYaw = false;

const int YAW_THRESHOLD = 5;   // tolerance in degrees
const int DIST_TRIGGER = 100;  // cm

// --- IMU ---
MPU6050 mpu;
int16_t ax, ay, az;
int16_t gx, gy, gz;

float yaw = 0;
unsigned long lastIMUTime = 0;    // for integration
unsigned long lastPrintTime = 0;  // for printing
const unsigned long PRINT_INTERVAL = 200; // ms

// --- Pines de los ultrasonicos ---
const int trigPin1 = 25;
const int echoPin1 = 26;
const int trigPin2 = 32;
const int echoPin2 = 33;

// --- Servo ---
Servo serv;
const int servoPin = 15;

// --- Motor DC ---
const int motorPin = 12;   // PWM velocidad
const int otherPin = 13;   // Dirección / freno
const int freq = 10000;    // 10 kHz
const int resolution = 8;  // 8 bits (0-255)
bool dirc = false;

const int SERVO_CENTER = 87;  // prueba: ajústalo hasta que vaya recto

bool out;

// Lectura robusta HC-SR04 (mediana de 3, pulldown)
static inline long medirUna(int trigPin, int echoPin) {
  unsigned long t = micros();
  while (digitalRead(echoPin) == HIGH && (micros() - t) < 2000) {}
  digitalWrite(trigPin, LOW);  delayMicroseconds(2);
  digitalWrite(trigPin, HIGH); delayMicroseconds(10);
  digitalWrite(trigPin, LOW);
  unsigned long dur = pulseInLong(echoPin, HIGH, 25000UL);
  if (dur == 0) return 400;
  long cm = (long)(dur * 0.0343f * 0.5f);
  if (cm < 3) return 400;
  return cm;
}
long medirDistancia(int trigPin, int echoPin) {
  long a = medirUna(trigPin, echoPin); delayMicroseconds(500);
  long b = medirUna(trigPin, echoPin); delayMicroseconds(500);
  long c = medirUna(trigPin, echoPin);
  if (a > b) { long t=a; a=b; b=t; }
  if (b > c) { long t=b; b=c; c=t; }
  if (a > b) { long t=a; a=b; b=t; }
  return b;
}

int counter = 0;

void IRAM_ATTR readEncoder() {
  int b = digitalRead(SB);
  if (b > 0) {
    pos++;
  } else {
    pos--;
  }
}

// --- Funciones Motor ---
void setMotorSpeed(int speed) {   
  digitalWrite(otherPin, LOW);
  ledcWrite(motorPin, speed);
}

void brakeMotor() {
  digitalWrite(otherPin, HIGH);
  ledcWrite(motorPin, 255);
  delay(100);
  ledcWrite(motorPin, 0);
}

void setup() {
  Serial.begin(115200);

  pinMode(SA, INPUT_PULLUP);
  pinMode(SB, INPUT_PULLUP);
  attachInterrupt(digitalPinToInterrupt(SA), readEncoder, RISING);

  Wire.begin(); 
  mpu.initialize();

  pinMode(trigPin1, OUTPUT);
  pinMode(echoPin1, INPUT);
  pinMode(trigPin2, OUTPUT);
  pinMode(echoPin2, INPUT);

  serv.attach(servoPin);
  serv.write(90);

  pinMode(otherPin, OUTPUT);
  ledcAttach(motorPin, freq, resolution);
  digitalWrite(otherPin, LOW);
  ledcWrite(motorPin, 255);
}

void loop() {
  // ====== Read ultrasonics ======
  long d1 = medirDistancia(trigPin2, echoPin2); // left
  long d2 = medirDistancia(trigPin1, echoPin1); // right

  unsigned long now = millis();
  unsigned long nowMicros = micros();

  // ====== IMU update (always, with real Δt) ======
  float dt = (nowMicros - lastIMUTime) / 1000000.0;  // seconds
  lastIMUTime = nowMicros;

  mpu.getMotion6(&ax, &ay, &az, &gx, &gy, &gz);
  float yaw_rate = (float)gz / 131.0; // deg/s
  yaw += yaw_rate * dt;

  // ====== Encoder update every 300 ms ======
  if (now - lastTimeza >= ENCODER_INTERVAL) {
    int delta = pos - lastPos;
    lastPos = pos;

    rpm = (delta / (float)PULSOS_POR_REV) * (60000.0 / ENCODER_INTERVAL);

    /*Serial.print("Posicion (pulsos): ");
    Serial.print(pos);
    Serial.print(" | RPM: ");
    Serial.println(rpm);*/

    lastTimeza = now;
  }

  // ====== Print yaw every 200 ms ======
  if (now - lastPrintTime >= PRINT_INTERVAL) {
    /*Serial.print("Yaw: ");
    Serial.println(yaw);*/
    lastPrintTime = now;
  }

  // --- ultrasonic steering ---
  int diff = d1 - d2;
  int servoAngle = map(diff, -20, 20, 80, 100);
  serv.write(constrain(servoAngle, 50, 120));

  // ====== Motor speed control ======
  float accelX_g = (float)ax / 16384.0;
  float accelX_ms2 = accelX_g * 9.81;
  int motorVel = map(accelX_ms2, -5, 5, 115, 255);
  motorVel = constrain(motorVel, 0, 255);
  digitalWrite(otherPin, LOW);
  ledcWrite(motorPin, motorVel);

  /*if (rpm == 0) {
    if(yaw > 0){
      serv.write(120);
      digitalWrite(otherPin, HIGH);
      ledcWrite(motorPin, 255);
      delay(2000);      
    }
    else if (yaw < 0){
      serv.write(60);
      digitalWrite(otherPin, HIGH);
      ledcWrite(motorPin, 255);
      delay(2000);        
    }
  }*/
}

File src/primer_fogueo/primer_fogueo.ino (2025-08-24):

// 6 turns: angle increases +SERVO_STEP_DEG° ONLY during the first 4 turns
// Features: reverse-kick on each turn, post-brake boost,
// dutyWork +30 after the first turn, and full brake at the 6th turn.
// Guarantee: servo at 90° before the motor spins at startup.

#include <ESP32Servo.h>

// ===== Pins =====
const int IN_PWM    = 12;   // Active PWM input (forward)
const int IN_OTHER  = 14;   // The other input: LOW in forward; PWM in reverse
const int SERVO_PIN = 19;   // Servo

// ===== PWM =====
const int PWM_FREQ  = 7000;     // (increase to 20000 if you want inaudible PWM)
const int PWM_RES   = 8;        // 0..255
const uint8_t DUTY_WORK = 70;   // Base duty for forward motion
const uint8_t DUTY_MAX  = 200;  // Maximum duty (boost)
int currentDutyWork = DUTY_WORK;

// ===== Servo / Turns =====
Servo servo;
const int SERVO_CENTER     = 90;
const int SERVO_RIGHT_BASE = 120; // base angle for the first turn
const int SERVO_STEP_DEG   = 2;   // increment per turn (limited to 4 turns)

// ===== Timings =====
const uint32_t WAIT_BEFORE_TURN_MS = 200;
const uint32_t HOLD_TURN_MS        = 790;
const uint32_t RETURN_TRAVEL_MS    = 350;
const uint32_t BOOST_AFTER_CENTER  = 300;
const uint16_t SERVO_SETTLE_MS     = 800;  // ensure 90° at startup

// ===== Brakes =====
const uint16_t REVERSE_KICK_TURN_MS = 120; // short reverse-kick on each turn
const uint16_t BOOST_AFTER_BRAKE_MS = 150; // short boost after braking
const uint16_t BRAKE_MS             = 180; // active brake (final stop)
const uint16_t REVERSE_KICK_MS      = 280; // long reverse-kick (final stop)

// ================= Motor helpers (IN1/IN2) =================
inline void coast_gpio_lowlow() {   // use BEFORE attaching PWM
  pinMode(IN_PWM, OUTPUT);
  pinMode(IN_OTHER, OUTPUT);
  digitalWrite(IN_PWM, LOW);
  digitalWrite(IN_OTHER, LOW);
}

inline void brakeHard() {           // IN1=1, IN2=1 (short bursts)
  digitalWrite(IN_OTHER, HIGH);
  ledcWrite(IN_PWM, 255);
}

inline void setForwardDuty(uint8_t duty) {
  digitalWrite(IN_OTHER, LOW);
  ledcWrite(IN_PWM, duty);
}

inline void boostForward(uint32_t ms, uint8_t duty = DUTY_MAX) {
  setForwardDuty(duty);
  delay(ms);
}

inline void reverseKick(uint8_t duty, uint32_t ms) { // short reverse
  ledcWrite(IN_PWM, 0);                      // IN_PWM=LOW
  ledcAttach(IN_OTHER, PWM_FREQ, PWM_RES);   // PWM on IN_OTHER (reverse)
  ledcWrite(IN_OTHER, duty);
  delay(ms);
  ledcWrite(IN_OTHER, 0);
  // restore forward mode
  pinMode(IN_OTHER, OUTPUT);
  digitalWrite(IN_OTHER, LOW);
  ledcAttach(IN_PWM, PWM_FREQ, PWM_RES);
}

// ================= Maneuver helpers =================
inline void waitBeforeTurn() { delay(WAIT_BEFORE_TURN_MS); }

inline void turnRightMaxPowerAngle(int angleDeg) {
  angleDeg = constrain(angleDeg, 0, 180);
  servo.write(angleDeg);
  boostForward(HOLD_TURN_MS);      // drive strongly while turning
}

inline void returnCenterMaxPower() {
  servo.write(SERVO_CENTER);
  delay(RETURN_TRAVEL_MS);         // still with strong power
}

inline void perTurnBrakeAndBoost() {
  reverseKick(DUTY_MAX, REVERSE_KICK_TURN_MS);   // short brake with reverse
  boostForward(BOOST_AFTER_BRAKE_MS, DUTY_MAX);  // small push forward
  setForwardDuty(currentDutyWork);               // return to work duty
}

inline void finalBrakeStop() {
  brakeHard();                          delay(BRAKE_MS);
  reverseKick(DUTY_MAX, REVERSE_KICK_MS);
  brakeHard();                          delay(BRAKE_MS);
  // stop in low/low state
  ledcWrite(IN_PWM, 0);
  digitalWrite(IN_OTHER, LOW);
}

// Ensure servo is at 90° before motor spins (only at startup)
inline void ensureServoCenteredBeforeStart() {
  servo.write(SERVO_CENTER);
  coast_gpio_lowlow();          // motor completely stopped (GPIO LOW/LOW)
  delay(SERVO_SETTLE_MS);       // time for servo to settle at 90°
}

// ================= Setup / Loop =================
void setup() {
  Serial.begin(115200);

  // Servo
  servo.setPeriodHertz(50);
  servo.attach(SERVO_PIN, 500, 2400);
  servo.write(SERVO_CENTER);

  // Ensure both driver inputs are LOW as GPIO (no PWM yet)
  coast_gpio_lowlow();

  // Guarantee servo at 90° BEFORE enabling motor PWM
  ensureServoCenteredBeforeStart();

  // Now: attach PWM to the active pin
  ledcAttach(IN_PWM, PWM_FREQ, PWM_RES);

  // Startup boost and initial duty
  boostForward(1000);
  setForwardDuty(currentDutyWork);

  Serial.println("Ready: servo centered before start; 6 turns with increment only in the first 4.");
}

void loop() {
  static int giro = 0;

  if (giro < 6) {
    // Increment angle only in the first 4 turns (index 0..3)
    int incIndex = (giro < 4) ? giro : 3;
    int angleThisTurn = SERVO_RIGHT_BASE + incIndex * SERVO_STEP_DEG;

    waitBeforeTurn();
    turnRightMaxPowerAngle(angleThisTurn);
    returnCenterMaxPower();
    perTurnBrakeAndBoost();

    // +30 duty after the FIRST turn
    if (giro == 0) {
      currentDutyWork = min(currentDutyWork + 30, 255);
      Serial.printf("Work duty increased to %d after first turn.\n", currentDutyWork);
    }

    giro++;

    // On the 6th turn, apply full stop and end
    if (giro == 6) {
      finalBrakeStop();
      Serial.println("Sequence of 6 turns completed and final brake applied. Stopped.");
    }
  } else {
    // Stopped
    delay(100);
  }
}

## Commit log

2025-08-14 Schematic
    First commit with the schematic design
2025-08-24 Primer Fogueo
    This are the changes we made on our first internal competition
    [001 top.STL, 001.SLDPRT, 001.STL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]
2025-09-19 Tercer Fogueo
    Update for our internal competition, changes to the readme uploaded videos and new 3D design models
    [01_RingGear.stl, 02_InputGear.stl, 03_PlanetGear.stl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]
2025-10-05 Previous Versions Update
    prototype versions
2025-10-05 fixed
    added the photos correctly and links in the BOM
2025-10-16 big update
    updated all readme files
    [01_RingGear.stl, 02_InputGear.stl, 03_PlanetGear.stl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]
2025-10-17 re organized files, added photos
    added photos and fixed readmes
    [001 top.STL, 001.SLDPRT, 001.STL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]
2025-10-18 UPDATE
    updates the final STL Files with all mechanical changes, updated team photos, updated info about the videos and updated home readme
    [001.SLDPRT, 001.STL, 608RS.SLDPRT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]
2025-10-19 update
    fixed pic size added old codes and updated the esp32 code for the open challenge
    [open-v1.ino, open-v2.ino, open-v3.ino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]
